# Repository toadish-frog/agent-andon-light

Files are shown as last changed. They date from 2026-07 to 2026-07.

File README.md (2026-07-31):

# Agent Andon Light





A physical desktop status light and vibe coding companion for Claude Code / CLI coding agents — so you can walk away while an agent works and still know its state at a glance, instead of staring at a terminal.

| | | | |
| :---: | :---: | :---: | :---: |
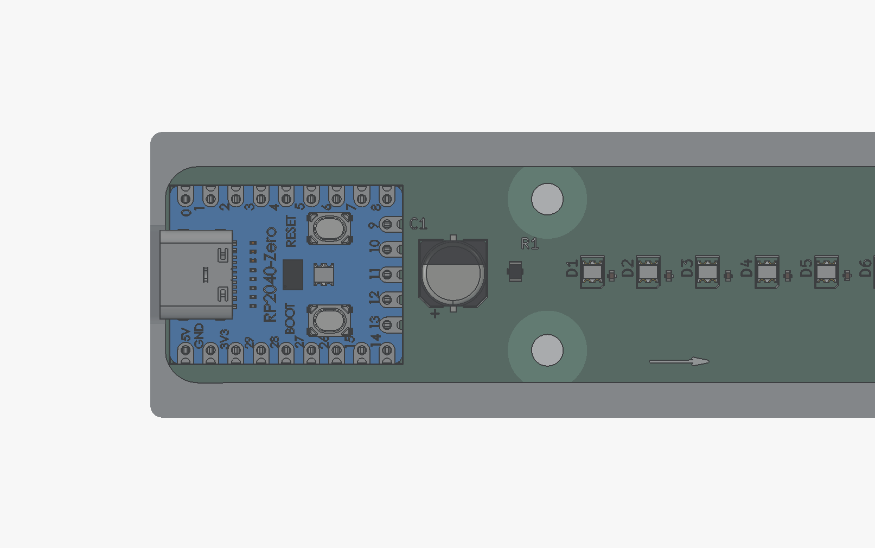
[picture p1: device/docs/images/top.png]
Top view
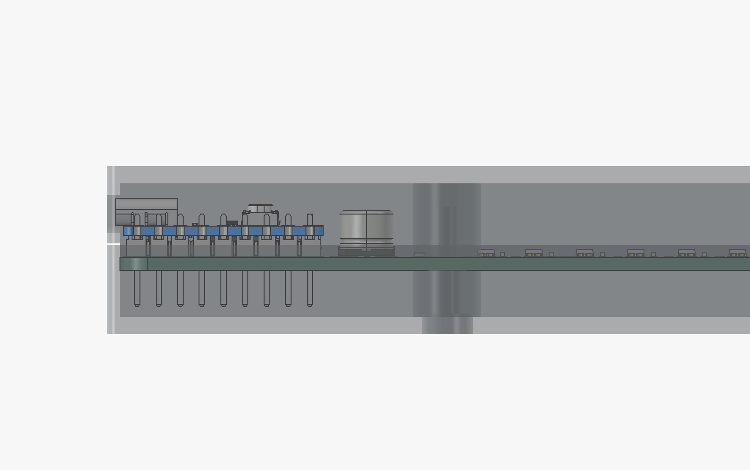
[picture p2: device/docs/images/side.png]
Side view
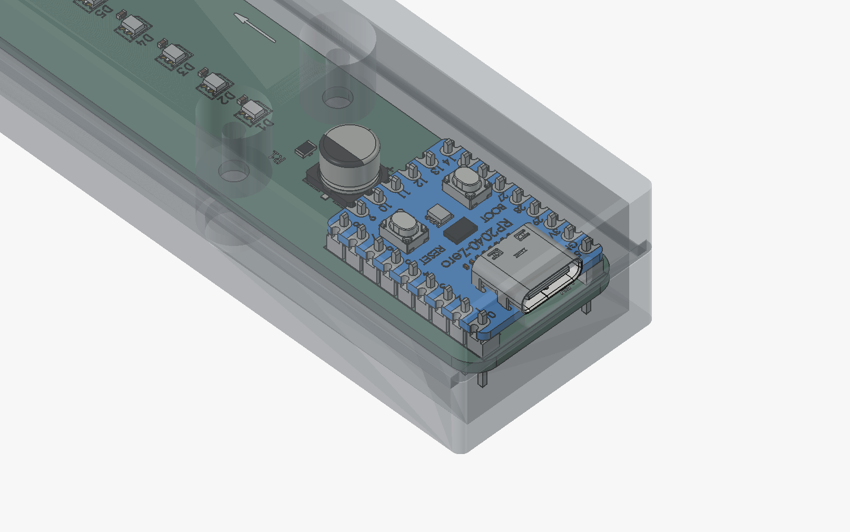
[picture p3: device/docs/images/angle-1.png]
Angle view
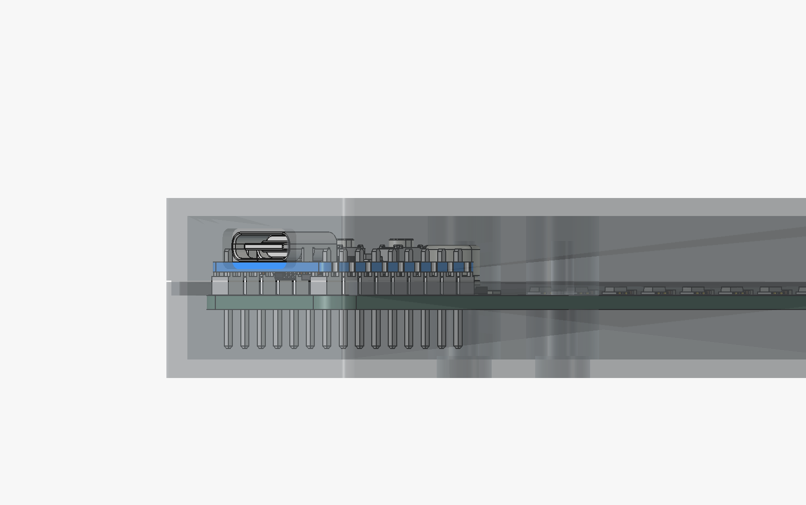
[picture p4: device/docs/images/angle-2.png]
Angle view
|  |  |  |  |

| | Color | Meaning |
| --- | --- | --- |
| 🟩 | Green | Agent working |
| 🟨 | Yellow | Waiting on you (permission or input) |
| 🟥 | Red | Idle / stopped / session ended |
| 🟩💫 | Flashing green | Compacting (internal maintenance, still alive) |
| 🟥〜 | Slow pulsing red | Stale / disconnected (device hasn't heard from the host in 30 min) |

This doc covers "I already have the hardware, how do I get it running." Building the hardware from scratch starts at [`device/docs/USER-GUIDE.md`](device/docs/USER-GUIDE.md).

## What You Need

- The assembled device — a Waveshare RP2040-Zero hand-soldered onto the custom PCB, **pre-flashed with firmware.** Building one from scratch instead? Start at [`device/docs/USER-GUIDE.md`](device/docs/USER-GUIDE.md), not here.
- A data-capable USB-C cable.
- Python 3 — Linux only. Windows doesn't need it; the installer is self-contained.

## Quick Start

**1. Plug in the device** with a data-capable USB-C cable.

**2. Install the host CLI.**

| OS | How |
| --- | --- |
| Linux | `pipx install andon-light` — see [`packaging/linux/README.md`](packaging/linux/README.md) |
| Windows | Download `andon-light-setup.exe` from [Releases](https://github.com/toadish-frog/agent-andon-light/releases) and run it — see [`packaging/windows/README.md`](packaging/windows/README.md) |

Confirm it can see the device:

```txt
andon-light doctor
```

**3. Wire up the Claude Code hooks:**

```txt
andon-light install-hooks
```

Shows you the exact hook config before touching anything, then merges it into `~/.claude/settings.json` (or a single project's config) once you confirm. Rationale for each hook mapping: [`hooks/README.md`](hooks/README.md).

**4. Restart Claude Code** (or start a new session) — hook config changes don't apply to a session already running.

From here the light tracks your session automatically — no manual commands needed day to day.

## Manual Control

Useful for testing, or to set the light by hand:

| Command | Effect |
| --- | --- |
| `andon-light set working` | 🟩 Solid green |
| `andon-light set waiting` | 🟨 Solid yellow |
| `andon-light set idle` | 🟥 Solid red |
| `andon-light set compacting` | 🟩💫 Chase-fill (compacting) |
| `andon-light heartbeat` | Keepalive, no color change |
| `andon-light doctor` | Detect the device and report its port |

## Troubleshooting

See [`device/docs/TROUBLESHOOTING.md`](device/docs/TROUBLESHOOTING.md) for the full diagnostic playbook, covering both Windows and Linux.

## Documentation

### Building & Hardware

- [User Guide](device/docs/USER-GUIDE.md) — build guide: soldering, wiring, glossary
- [Bill of Materials](device/docs/BOM.md) — parts list
- [Firmware](device/firmware/README.md) — firmware setup & wire protocol

### Software

- [Host CLI](host/README.md) — CLI development & usage
- [Claude Code Hooks](hooks/README.md) — hook mapping & rationale

### Installing

- [Linux Install](packaging/linux/README.md)
- [Windows Install](packaging/windows/README.md)

### Troubleshooting

- [Diagnostic Playbook](device/docs/TROUBLESHOOTING.md) — Windows + Linux

### Archive

- [3-Bulb MVP](archive/led-bulb-mvp/README.md) — earlier hardware iteration, not part of the current build

## Project Structure

```txt
agent-andon-light/
├── device/                 the only ongoing hardware line
│   ├── firmware/            Arduino sketch (C++) — drives the LED strip
│   ├── hardware/             KiCad schematic, PCB, manufacturing files
│   └── docs/                  BOM, user guide, troubleshooting, images
├── host/                   Python CLI (`andon-light`) — talks to the firmware over USB serial
├── hooks/                  Claude Code hook config that drives the CLI automatically
├── packaging/              OS-specific install/build tooling
│   ├── linux/                docs-only install path (pipx, no build step)
│   └── windows/               PyInstaller build + Inno Setup installer
├── scripts/                misc dev/demo scripts
└── archive/                retired hardware iterations, frozen history
    └── led-bulb-mvp/          3-discrete-bulb MVP, superseded by the strip
```

## Status

5 units built and tested — custom PCB, 3D-printed enclosure, firmware, host CLI, and Claude Code hooks all confirmed working end to end. Published on PyPI; a one-click Windows installer is available.

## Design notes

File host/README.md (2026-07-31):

# Host CLI: andon-light

Python driver for the Agent Andon Light. Talks to the firmware ([`../device/firmware/`](../device/firmware/)) over USB CDC serial via a simple text wire protocol.

## Layout

```txt
host/
├── pyproject.toml
├── andon_light/
│   ├── cli.py               # argparse entry point, `andon-light` command
│   ├── device_discovery.py  # finds the board by USB vendor ID
│   ├── serial_link.py       # opens/writes the serial connection, retry-on-busy
│   ├── hooks_install.py     # `andon-light install-hooks` merge/confirm logic
│   └── data/
│       └── settings.snippet.json   # bundled copy for installed/frozen builds
└── tests/
    └── test_hooks_install.py
```

## Install (development)

For actually using the CLI (Claude Code hooks, manual `andon-light` calls), install the published package instead — see [`../packaging/linux/README.md`](../packaging/linux/README.md) (Linux) or [`../packaging/windows/README.md`](../packaging/windows/README.md) (Windows). macOS isn't tested or supported yet.

To develop this repo, install in editable mode — symlinks back to source, so edits show up immediately without reinstalling:

```txt
cd host
pipx install --editable .
```

For an isolated venv, not on `PATH` outside it:

```txt
cd host
python3 -m venv .venv
.venv/bin/pip install -e .
```

## Usage

```txt
andon-light doctor                              # detect the device
andon-light set working                         # solid green
andon-light set waiting                         # solid yellow
andon-light set idle                             # solid red
andon-light set compacting                       # flashing green
andon-light heartbeat                            # keepalive, no color change
andon-light --port /dev/ttyACM0 set working      # override auto-detection
andon-light install-hooks                        # merge Claude Code hooks into settings.json
andon-light install-hooks --yes --scope global   # same, non-interactive (used by the Windows installer)
```

`install-hooks` prints the exact `hooks` block before touching anything, asks for confirmation, lets you pick global (`~/.claude/settings.json`) vs. project (`./.claude/settings.json`) scope, and warns before overwriting any hook event you've already customized. It never edits silently — see [`../hooks/README.md`](../hooks/README.md).

## Notes

- Auto-detection (`device_discovery.py`) filters by USB vendor ID `0x2E8A` (Raspberry Pi Foundation, used by arduino-pico's default TinyUSB descriptor) — matches the Waveshare RP2040-Zero.
- Override with `--port` or the `ANDON_LIGHT_PORT` env var if auto-detection picks the wrong port or finds nothing.
- "Device or resource busy" means another process (e.g. Arduino IDE's Serial Monitor) has the port open — only one process can hold it at a time. `andon-light` retries automatically for ~450ms before giving up; a serial failure then prints a one-line message with exit code 1 instead of a raw Python traceback.

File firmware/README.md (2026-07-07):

# Firmware — Agent Andon Light

Arduino sketch for the Waveshare RP2040-Zero, implementing the v2 wire protocol from `.prompt/docs/Implementation-Summary.md` (`G`/`Y`/`R`/`C`/`H`).

## Setup (once — see `.prompt/docs/USER-GUIDE.md` Phase 1 checklist)

1. Arduino IDE 2.x, with the `arduino-pico` board package installed. No LED library needed — the 3 status bulbs are plain `digitalWrite`/`analogWrite` GPIO, not an addressable protocol.
2. Open `andon_light_firmware/andon_light_firmware.ino` — Arduino IDE will load `led_controller.h/.cpp` and `watchdog.h` alongside it as tabs.

## Wiring

The status light is a custom PCBA with 3 discrete LED bulbs (Red/Yellow/Green) and a 4-pin connector: `GND`, `Red`, `Yellow`, `Green`.

- PCBA `GND` ← board `GND`
- PCBA `Green` ← `GPIO1`
- PCBA `Yellow` ← `GPIO2`
- PCBA `Red` ← `GPIO3`

Change the pins in `andon_light_firmware.ino` by editing `kGreenPin`/`kYellowPin`/`kRedPin` if you wire it differently. Note the RP2040-Zero uses plain GPIO numbers (`GPIO0`, `GPIO1`, ...), not the `D0`-style aliases Seeed's boards use — don't copy pin names from XIAO tutorials verbatim.

## Flash & test

1. Select "Waveshare RP2040-Zero" as the board, then flash.
2. Open the Serial Monitor at 115200 baud, line ending "Newline".
3. Type `G`, `Y`, `R` and press enter — confirm the LEDs respond. To test the stale-pulse fallback without waiting the full 30 minutes, temporarily lower `kWatchdogTimeoutMs` (e.g. to `15000`), flash, confirm the slow red pulse kicks in after that shorter wait, then change it back to `1800000` and reflash.

## Confirmed on real hardware (2026-07-07)

- `kGreenPin`/`kYellowPin`/`kRedPin` (`GPIO1`/`GPIO2`/`GPIO3`) — confirmed correct against the actual PCBA wiring via Serial Monitor testing.
- `StalePulse`'s `analogWrite` (PWM) breathing animation on the red pin — confirmed working on GPIO3.

## New in v2: flashing green (`C`)

Added 2026-07-07 alongside the `PostCompact` hook, for "still working, just doing internal context compaction" — visually distinct from solid green (`G`, ordinary working) via a sharp on/off blink (`kFlashPeriodMs = 500` in `led_controller.cpp`), as opposed to `StalePulse`'s slow smooth breathing fade. **Needs re-flashing** to take effect — this is source-level only until the sketch is re-uploaded.

## Power-on default: idle (red), not off

Added 2026-07-08 — the board's `setup()` used to leave all 3 bulbs off until the first serial command arrived. That's fine when Claude Code's `SessionStart` hook fires right after, but a bare USB replug/power-cycle is a hardware event Claude Code never sees, so the light would sit dark indefinitely until some other hook happened to fire. `LedController::begin()` now boots straight to `LightColor::Red` (idle) instead of `Off`, matching the same "not working yet" default reasoning as the `SessionStart` hook. **Needs re-flashing** to take effect. Note: replugging the USB cable does **not** erase or require re-flashing the firmware itself (it's stored permanently in flash memory) — this fix is only about what color it happens to boot into, not whether the program is still there.

## Watchdog timeout: 30 minutes, not 15 seconds

Originally 15s, raised to `kWatchdogTimeoutMs = 1800000` (30 min) after real-world testing with Claude Code hooks showed false stale-pulse trips: the hooks only fire at a few discrete moments (prompt submitted, tool used, waiting, stopped), so any gap longer than 15s between them — e.g. a long stretch of the model just thinking with no tool calls — incorrectly looked "disconnected." 30 minutes comfortably covers that while still eventually recovering if a session is genuinely abandoned mid-turn. See `../hooks/README.md` for the corresponding `PreToolUse` hook addition that keeps the watchdog kicked during tool-heavy stretches.

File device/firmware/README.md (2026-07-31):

# Firmware: Agent Andon Light

Arduino sketch for the Waveshare RP2040-Zero — drives a 10-LED addressable WS2812 strip via Adafruit_NeoPixel, speaking the wire protocol below over USB serial.

An earlier iteration used 3 discrete bulbs instead of an addressable strip — see [`../../archive/led-bulb-mvp/firmware/`](../../archive/led-bulb-mvp/firmware/) for that firmware, preserved but not maintained.

**This doc covers firmware only** (code, dependency, flashing, protocol). For physically building the device — soldering, wiring — see [`../docs/USER-GUIDE.md`](../docs/USER-GUIDE.md), the single source of truth for hardware assembly.

## Contents

- [Dependency: Adafruit_NeoPixel](#dependency-adafruit_neopixel)
- [Setup](#setup)
- [Flash & Test](#flash--test)
- [Reference](#reference)
  - [Power](#power)
  - [Pixel Layout](#pixel-layout)
  - [Wire Protocol Reference](#wire-protocol-reference)

## Dependency: Adafruit_NeoPixel

WS2812-style LEDs need sub-microsecond bit timing that plain `digitalWrite`/`analogWrite` can't produce. This sketch uses **Adafruit_NeoPixel** (Arduino Library Manager → search "Adafruit NeoPixel" → Install) — the standard driver for this chip family, with native RP2040/PIO support via `arduino-pico`.

## Setup

1. Arduino IDE 2.x, with the `arduino-pico` board package installed.
2. Install the Adafruit NeoPixel library (Tools → Manage Libraries).
3. Open `andon_light_firmware/andon_light_firmware.ino` — Arduino IDE loads `led_controller.h/.cpp` and `watchdog.h` alongside it as tabs.

Building the physical board (soldering the MCU on, or wiring a breadboard prototype) happens in [`../docs/USER-GUIDE.md`](../docs/USER-GUIDE.md) §2, before you get to Flash & Test below.

## Flash & Test

1. Select "Waveshare RP2040-Zero" as the board, then flash.
2. Open the Serial Monitor at 115200 baud, line ending "Newline".
3. Confirm pixel 1 alone is dim white and pixels 2-10 are dark (boot state).
4. Type `G`, `Y`, `R`, pressing enter after each — confirm only that color's 3-pixel section lights, rest stays dark.
5. Type `C` — confirm the chase-fill sweep described in [Pixel Layout](#pixel-layout) below.
6. To test `StalePulse` without waiting 30 minutes: temporarily set `kWatchdogTimeoutMs` to `15000`, flash, confirm the breathing red pulse on pixels 8-10, then set it back to `1800000` and reflash.

## Reference

### Power

Brightness is capped at `kBrightness = 130/255` (`led_controller.cpp`) for current draw and eye comfort — raise it if the strip is diffused behind a cover. If you're seeing flicker or wrong colors, that's a hardware issue (solder joint or wiring, depending on your build) — see [`../docs/USER-GUIDE.md`](../docs/USER-GUIDE.md) Pitfalls to Avoid, not a firmware setting.

### Pixel Layout

| Pixel | Role | Color |
| --- | --- | --- |
| 1 | Status, always on | Dim white |
| 2-4 | Green section | `G` → RGB(0,255,0) |
| 5-7 | Yellow section | `Y` → RGB(255,255,0) |
| 8-10 | Red section | `R` → RGB(255,0,0); watchdog stale → breathing red |

- Pixel 1 stays dim white through every state, including `Off` — a "board powered, firmware running" indicator, independent of the `G`/`Y`/`R` state color.
- `G`/`Y`/`R` each light only their own section; every other section (except pixel 1) goes dark.
- `StalePulse` (watchdog timeout) breathes the red section (8-10) with the same cosine curve, confined to that section.
- `CompactFlash` uses all 9 non-status pixels (2-10): a single lit pixel sweeps from pixel 10 down to pixel 2 and locks, the next sweep locks pixel 3 (skipping the now-locked pixel 2), and so on — pixels accumulate lit from pixel 2 upward, one per pass, until all 9 are lit, then it resets and repeats. See `kCompactPixelCount`/`kCompactStepMs` in `led_controller.cpp`.

See `led_controller.cpp`'s `kGreenStart`/`kYellowStart`/`kRedStart`/`kStatusPixel` constants for the implementation.

### Wire Protocol Reference

| Command | Effect | Meaning |
| --- | --- | --- |
| `G\n` | Pixels 2-4 solid green | Agent working |
| `Y\n` | Pixels 5-7 solid yellow | Waiting for human input / permission |
| `R\n` | Pixels 8-10 solid red | Idle / stopped / quota reached |
| `C\n` | Chase-fill across pixels 2-10 | Compacting — internal maintenance, still alive |
| `H\n` | No color change | Heartbeat, resets the watchdog |

Watchdog timeout: **30 minutes**.

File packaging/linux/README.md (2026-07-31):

# Linux Install & Verify

No installer to build — Linux is docs-only by design, published straight to PyPI. Linux users are assumed comfortable with a terminal.

## 1. Install

```txt
sudo apt install -y pipx   # if you don't have pipx yet
pipx install andon-light
```

No repo clone needed.

## 2. Verify

```txt
andon-light doctor
```

Confirms the CLI can find the board. If it reports a permission error, your user needs `dialout` group membership — see [`../../device/docs/TROUBLESHOOTING.md`](../../device/docs/TROUBLESHOOTING.md) Linux-Specific section.

## 3. Wire Up Claude Code Hooks

```txt
andon-light install-hooks
```

Prints the exact `hooks` block before touching anything, asks for confirmation, and lets you pick global (`~/.claude/settings.json`) vs. project (`./.claude/settings.json`) scope — see [`../../hooks/README.md`](../../hooks/README.md).

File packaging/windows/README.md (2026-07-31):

# Windows Installer: Build & Test

Everything here needs to run on Windows — build it there, not by cross-compiling from Linux.

## 1. Build the .exe

Prerequisites: Python 3.9+ on `PATH`.

```powershell
.\packaging\windows\build.ps1
```

Creates an isolated build venv at `packaging\windows\.build-venv` (doesn't touch any Python install you already have), builds `packaging\windows\dist\andon-light.exe` via PyInstaller, prints its size, and runs `andon-light.exe doctor` as a sanity check.

**Expected size:** low tens of MB — PyInstaller only bundles what's reachable from the entry point (`argparse` + `pyserial`, nothing exotic). If the size is much larger, check `packaging\windows\build\andon-light\warn-andon-light.txt` (PyInstaller's build log) for what got pulled in.

## 2. Build the Installer

Prerequisite: [Inno Setup](https://jrsoftware.org/isinfo.php).

```powershell
iscc packaging\windows\andon-light.iss
```

(Or open `andon-light.iss` in the Inno Setup IDE and click Compile.) Output: `packaging\windows\dist\andon-light-setup.exe`.

| Property | Behavior |
| --- | --- |
| Privilege | Per-user, no admin/UAC prompt |
| PATH | Adds itself to the user's `PATH` |
| Hooks | Finish-page checkbox runs `andon-light.exe install-hooks` — same confirm-before-writing flow as the CLI's interactive mode, see [`../../hooks/README.md`](../../hooks/README.md) |

## 3. SmartScreen Warning

Neither `andon-light.exe` nor `andon-light-setup.exe` is code-signed. Windows shows "Windows protected your PC" the first time either runs, and some antivirus engines may flag the PyInstaller `--onefile` binary outright — its self-extract-to-temp-dir behavior at runtime resembles a malware dropper. Neither means the build is broken.

| | |
| --- | --- |
| Fix | Click "More info," then "Run anyway." |
| Affects | Every recipient, not just test runs — pass along the click-through instructions with the installer. |
| Real fix, if ever needed | An Authenticode code-signing certificate (~$70–400/yr) removes the "Unknown Publisher" label; a new cert still needs to build SmartScreen reputation over time unless it's EV. Not worth it for a handful of known recipients. |

## 4. Verification Checklist

Test on real Windows hardware, not by inspection:

- [ ] **CDC driver** — RP2040-Zero enumerates as a COM port with zero extra steps, no `arduino-pico` INF needed.
- [ ] **PATH** — open a **new** terminal after installing (PATH changes don't apply to already-open ones) and confirm `andon-light doctor` resolves and finds the device.
- [ ] **install-hooks from the finish page** — checkbox launches a visible console window with the interactive prompt; declining/confirming both behave as expected.
- [ ] **Uninstall** — "Add or Remove Programs" cleanly removes both the `PATH` entry and the installed files. Inno Setup doesn't undo a `[Registry]` string append automatically — `andon-light.iss` has explicit `RemovePath`/`CurUninstallStepChanged` logic for this; verify it actually works.

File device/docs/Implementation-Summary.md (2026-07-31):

# Implementation Summary: Agent Andon Light

Internal reference for tech stack, architecture, and roadmap — dev/agent-facing, not tracked on the remote for outside readers. Update as decisions change.

The addressable WS2812 strip (`device/`) is the sole ongoing hardware line. An earlier 3-discrete-bulb MVP is archived at [`../archive/led-bulb-mvp/`](../archive/led-bulb-mvp/) — not a second deliverable, see History below for why it exists.

---

## 1. Technology Stack

### Hardware

| Part | Choice | Why |
| --- | --- | --- |
| MCU board | Waveshare RP2040-Zero | Native USB (no separate USB-UART chip), 23.5×18mm with castellated pads (hand-solderable), USB-C. Fully supported by Arduino IDE via `arduino-pico`. Onboard WS2812 RGB LED lets firmware/toolchain be smoke-tested before wiring anything external. |
| Status LEDs | Custom PCBA, WS2812-style addressable strip, 10 LEDs, wired via 3-pin connector (`S`/`V`/`G`) | Individually addressable per pixel over one data wire (`Adafruit_NeoPixel`), so each agent state owns a dedicated 3-pixel section instead of one shared color — see [Addressable Pixel Layout](#addressable-pixel-layout). |
| Cable / connector | 3-conductor wire or JST-style connector, plus a data-capable USB-C to USB-A cable to the host | 3 wires (`S`/`V`/`G`) MCU→strip; USB-C carries power + serial to the host. |
| Enclosure | 3D-printed diffuser + base | Passes light through 9 individually visible segments, not 3 discrete bulb positions. |

Full parts list: [`BOM.md`](BOM.md).

### Firmware

- **Language:** C++ (Arduino framework).
- **Library:** Adafruit_NeoPixel — required for WS2812 timing; can't be bit-banged reliably with plain GPIO calls.
- **Toolchain:** Arduino IDE (or Arduino CLI) with the `arduino-pico` board package.
- **Interface:** USB CDC serial — enumerates as a plain serial port on every OS, no custom driver needed on any of them.
- **Power:** must be 5V/`VBUS`, not 3.3V — 10 addressable LEDs draw meaningfully more current than a 3.3V regulator is meant to supply. Firmware caps brightness (`kBrightness = 130/255`) for draw and eye comfort.

### Host Driver Software

- **Language:** Python 3 — runs identically on Linux/Windows/macOS with minimal setup; `pyserial` + `pipx install andon-light` is far less friction than distributing compiled binaries per OS.
- **Key library:** `pyserial`.
- **Packaging:** pip-installable package (`andon-light`) exposing a CLI, published on PyPI.
- **Integration point:** Claude Code [Hooks](https://docs.claude.com/) — mapping and rationale in [`../../hooks/README.md`](../../hooks/README.md). Commands run synchronously (not `async`) — see History for why.
- **Known gap:** no hook fires on a user-initiated Esc/interrupt — not exposed by Claude Code's hook system. The light holds its last color through an Esc interrupt.
- **Unaffected by which firmware is flashed.** `host/andon_light/cli.py` maps each state to a single ASCII byte (`G`/`Y`/`R`/`C`) and writes it to whatever serial port `device_discovery.py` found — it has no idea how many LEDs are on the other end or how they're wired. That logic lives entirely in firmware. This is why `host/` and `hooks/` needed zero changes when the project moved from the bulb MVP to the strip.

---

## 2. Architecture

```txt
┌─────────────────────────┐
│  Claude Code / CLI agent│
│  (hooks fire on events) │
└───────────┬─────────────┘
            │ shell exec
            ▼
┌───────────────────────────┐
│  andon-light CLI (Python) │  ← ../../host/
└───────────┬───────────────┘
            │ USB CDC serial (identical text protocol)
            ▼
┌───────────────────────────┐
│  Firmware (C++/Arduino)   │  ← firmware/andon_light_firmware/
│  - parses commands        │
│  - drives 10 WS2812 pixels│
│    via Adafruit_NeoPixel  │
│  - watchdog / auto-idle   │
└───────────┬───────────────┘
            │ 1 GPIO data pin (+ 5V, GND)
            ▼
┌───────────────────────────┐
│  Custom PCBA, WS2812 strip│
│  10x addressable LEDs     │
└───────────────────────────┘
```

**Wire protocol:**

| Command | Effect |
| --- | --- |
| `G\n` | Working — green section solid |
| `Y\n` | Waiting — yellow section solid |
| `R\n` | Idle — red section solid |
| `C\n` | Compacting — chase-fill sequence |
| `H\n` | Heartbeat — no color change, resets watchdog |

**Reliability:** the firmware runs a watchdog timer — no heartbeat/command within **30 minutes** falls back to a slow-pulse red on the red section ("stale/disconnected") rather than silently freezing on a stale color if the host driver crashes. See History for how the timeout value was tuned.

### Addressable Pixel Layout

Each agent state owns a dedicated sub-range of the strip, rather than setting every pixel to the same color:

| Pixels (1-indexed) | Role | Color |
| --- | --- | --- |
| 1 | Status — always on | Dim white |
| 2-4 | Green section | `G` → solid green |
| 5-7 | Yellow section | `Y` → solid yellow |
| 8-10 | Red section | `R` → solid red; watchdog stale → breathing red (`StalePulse`) |
| 2-10 (all 9 non-status) | `C` (`CompactFlash`) | Chase-fill, not confined to one section |

For `G`/`Y`/`R`/`StalePulse`, only the active section's pixels are lit; every other section is off. Pixel 1 stays dim white through every state, including `Off`, as a constant "board is powered and firmware is running" indicator.

`CompactFlash` chase-fill spans all 9 non-status pixels: a single lit pixel sweeps from pixel 10 down to pixel 2 and locks, the next sweep locks pixel 3 (2 stays lit), and so on — pixels accumulate lit from pixel 2 upward, one per pass, until all 9 are lit, then it resets and repeats. This is a deliberately different rendering path from the other four states (`renderSection()` in `led_controller.cpp` doesn't cover it, since it needs two disjoint lit ranges at once).

**Boot behavior:** the strip boots to `Off` — dim-white status pixel only — since the status pixel alone already serves the "alive" signal, with no need to guess a placeholder state color.

---

## 3. Project Directory Structure

```txt
agent-andon-light/
├── README.md                   # top-level orientation + quick start
├── host/                        # Python driver package (andon-light CLI)
├── hooks/                       # Claude Code integration (settings.snippet.json + README)
├── packaging/                    # OS-specific distribution — windows/, linux/
└── device/                      # the only hardware line
    ├── firmware/
    │   ├── README.md
    │   └── andon_light_firmware/
    │       ├── andon_light_firmware.ino
    │       ├── led_controller.h/.cpp
    │       └── watchdog.h
    ├── hardware/                # KiCad schematic/PCB/manufacturing files — Rev A sent to JLC for fab
    │   ├── kicad/
    │   └── manufacturing/
    ├── archive/
    │   └── led-bulb-mvp/         # frozen 3-discrete-bulb breadboard MVP: firmware + docs
    └── docs/
        ├── BOM.md
        ├── Implementation-Summary.md   # this file
        ├── USER-GUIDE.md
        └── TROUBLESHOOTING.md
```

---

## 4. Roadmap

| # | Goal | Status |
| --- | --- | --- |
| 0 | Research & order parts | Done |
| 1 | Breadboard MVP (bulb PCBA, archived) | Done |
| 2 | Host CLI MVP | Done |
| 3 | Claude Code hook integration | Done |
| 4 | Reliability pass | Mostly done — live unplug/replug + long-turn stress test still outstanding |
| 5 | Custom PCB (strip) | Done — Rev A back from JLC, assembled, reflashed, electrically verified across all 5 units |
| 6 | Enclosure | Done — chassis base + lid 3D-printed via JLC, fit confirmed first-try on all 5 units |
| 7 | Packaging & distribution | Mostly done — PyPI published, `install-hooks` shipped, Windows installer built and verified on real hardware; Linux is docs-only by design, macOS deferred; GitHub release still outstanding |
| 8 | Stretch goals | Backlog — multi-agent/multi-light support, buzzer for alerts, ambient-light brightness sensing, user-configurable color mapping |

---

## 5. Open Items

- **Final brightness value** — `130/255` is a reasoned starting point (current draw + eye comfort), workable behind the actual diffuser, but not formally re-tuned against it.
- **Dim-white status pixel level** — `kDimWhiteLevel = 25` (pre-`kBrightness`-scaling) is a reasoned guess, not explicitly confirmed as the right dimness.
- **Per-unit cost at production quantity** — the 5-board sample order (PCB + assembly + enclosure) was priced well above what a larger MOQ run would cost; no clean per-unit figure logged.
- **macOS support** — deferred, no Apple hardware available to build, sign, or test on. Code-signing/notarization requirements unresearched.
- **`v0.1.0` GitHub release** — not yet cut. Last remaining item in Phase 7.

---

## 6. History

Chronological log of decisions and resolutions — the detail that used to be scattered across every section above now lives here instead.

| Date | Event |
| --- | --- |
| 2026-07-05 | Kickoff. MCU decision: Waveshare RP2040-Zero over XIAO RP2040 / Arduino Pro Micro clone. |
| 2026-07-07 | Bulb-MVP breadboard (Phase 1) flashed and confirmed: `G`/`Y`/`R` correct on physical bulbs, watchdog stale-pulse confirmed. Host CLI MVP (Phase 2) done: `andon-light doctor` auto-detected the board (`DEFAULT_VID = 0x2E8A`, confirmed via `udevadm`); `set working/waiting/idle` confirmed end-to-end. Claude Code hook integration (Phase 3) done: merged into `~/.claude/settings.json`, hook-to-color mapping fine-tuned same day. Reliability pass: hardened `host/andon_light/` error handling (clean one-line message + exit 1 instead of raw traceback), added retry-on-busy-port logic. Watchdog timeout raised from an initial 15s to 30 minutes after real Claude Code sessions showed false stale-triggers during long tool-call-free thinking stretches; `PreToolUse` hook added to keep the watchdog kicked during tool-heavy stretches. |
| 2026-07-08 | `SessionEnd` hook added — `Stop` alone doesn't fire on a user interrupt (Ctrl+C). `async: true` tried and reverted — caused hook commands to complete out of order, leaving the light on a stale color. |
| 2026-07-11 | Strip's own breadboard validation done (ahead of committing to a PCB layout): `kDataPin` confirmed as `GPIO1`; data-line signal integrity at 3.3V logic confirmed fine with a series resistor (level shifter kept as an available fallback); section boundaries (1 status + 3 green + 3 yellow + 3 red) confirmed against the physical 10-pixel strip; `CompactFlash` chase-fill flashed and confirmed working. Bulb variant's own Phase 5 (custom PCB) put on hold in favor of the strip going first. |
| 2026-07-14 | Project restructured: retired the parallel `led-bulb/`/`led-strip/` hardware tracks. Strip renamed from `led-strip/` to `device/` as the sole ongoing hardware line. Bulb MVP archived at `archive/led-bulb-mvp/`. |
| 2026-07-30 | Rev A PCB (5-board sample run) back from JLC — all 5 assembled, reflashed, and individually confirmed working: `G`/`Y`/`R`/`C` correct on the fabricated PCB's own traces, and `StalePulse` triggered and confirmed on real hardware for the first time (previously validated by code inspection only). Enclosure (chassis base + lid) 3D-printed via JLC alongside the PCB order — fit correct first-try on all 5 units, no reprint or redesign needed. Level-shifter footprint confirmed unnecessary on real hardware, left unpopulated. `andon-light` published to PyPI (v0.1.0, MIT licensed). `install-hooks` CLI subcommand shipped. |
| 2026-07-31 | Windows installer (PyInstaller + Inno Setup) built and verified on real Windows hardware: device enumerates as a COM port with zero extra driver steps, PATH resolves in a new terminal, `install-hooks` finish-page flow and uninstall (including a PATH-cleanup fix) both confirmed working. |

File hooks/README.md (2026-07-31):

# Claude Code Hook Integration: Agent Andon Light

`settings.snippet.json` maps agent events to `andon-light` CLI calls.

## Hook → Color Mapping

| Hook event | Color | Meaning |
| --- | --- | --- |
| `SessionStart` | idle (red) | Default state — a new session starts "not working yet" |
| `UserPromptSubmit` | working (green) | You just gave it something to do |
| `PreToolUse` | working (green) | Fires on every tool call — keeps the light green through tool-heavy stretches |
| `Notification` | waiting (yellow) | General "needs your attention" |
| `PermissionRequest` | waiting (yellow) | Specifically waiting on a permission decision (e.g. approve a `Bash`/`npm install` call) |
| `PreCompact` | flashing green (compacting) | Internal context compaction — still "alive," distinct from ordinary working |
| `Stop` | idle (red) | Turn/session ended normally |
| `SessionEnd` | idle (red) | Session terminated for any reason, including abrupt ones `Stop` doesn't cover |

Commands run synchronously, not `async` — see [Why Not `async`](#why-not-async) below. The `hooks` object from `settings.snippet.json` merges into `~/.claude/settings.json` (global) or a project's `.claude/settings.json`. This config has no visibility into what's wired up on the far side of the serial link — it just runs `andon-light` commands, and firmware ([`../device/firmware/`](../device/firmware/)) does the rest. Restart Claude Code (or start a new session) to pick up a config change.

## Design Notes

### `PreToolUse` Keeps the Watchdog Fed

`UserPromptSubmit`/`Notification`/`Stop` only fire at 3 discrete moments — nothing resets the firmware watchdog during a long stretch of tool calls in between, so the light can fall back to the stale/disconnected pulse mid-turn. `PreToolUse` fires on every tool invocation (reads, edits, bash commands) and sends `working`, so any tool-heavy turn keeps kicking the watchdog continuously. It doesn't cover a turn that's pure extended thinking with zero tool calls — there's no hook event for "still generating text" — so that gap is instead covered by a much longer firmware watchdog timeout (30 minutes); see [`../device/firmware/README.md`](../device/firmware/README.md).

### `PermissionRequest` vs. `Notification`

`PermissionRequest` is more precise than `Notification` alone for the specific "waiting on a permission approval" moment (e.g. approving a `Bash(npm install)` call). Both map to the same yellow action, so there's no harm in the overlap when `Notification` also fires for the same event.

### `PreCompact` Gets Its Own Color

Without a distinct color, a compaction pass would either stay on whatever color was last set (misleading if it was red/idle) or require another hook just to flip back afterward. Flashing green reads as "still alive, doing upkeep" at a glance, and naturally reverts to solid green (or whatever's next) once the following hook fires — no extra "compaction done" hook needed.

### `SessionStart` Makes the Default Deterministic

Without it, a new session inherits whatever color the previous session left behind — usually fine, since `Stop` already leaves it on idle/red, but not guaranteed if a prior session crashed mid-turn without a clean `Stop`. Setting idle explicitly on `SessionStart` removes that dependency on history.

### `SessionEnd` Catches Interrupts `Stop` Doesn't

Killing an active `claude` process with Ctrl+C (not just interrupting a turn) leaves the light stuck on whatever color was last set if only `Stop` is configured — `Stop` doesn't fire on user interrupts. `SessionEnd` fires on any termination reason (no matcher needed) and resets to idle (red). `Stop` stays alongside it so normal turn/session ends still resolve as fast as possible, without waiting on session teardown.

## Why Not `async`

Every command was originally `async: true`, to guarantee zero latency on real tool calls. `async` gives no ordering guarantee between hook invocations — only that each one is *launched* in order, not that it *finishes* in order. Each `andon-light set ...` call is a fresh Python process (spawn + import + open/close the serial port), measured at ~40-50ms — cheap, but not zero, and under load (e.g. a busy tool-heavy turn) that's enough jitter for a later-launched command to finish before an earlier one. Concretely: a session ends correctly on red (`Stop`), but a `Notification`/`PermissionRequest` command that fired earlier in the session had been delayed, and completes only after `Stop`'s `idle` command already landed — silently overwriting it with stale yellow.

Removing `async` makes Claude Code wait for each hook to finish before continuing, guaranteeing true event order. At ~40-50ms per call this isn't perceptible against real tool-call durations, so the latency `async` was meant to buy wasn't worth the ordering risk.

## Why Every Command Ends in `|| true`

If the board is ever unplugged or the CLI is run on a machine without it, every hook invocation would otherwise fail loudly in Claude Code's hook output on every single prompt — noisy and disruptive for something meant to be a passive status indicator. Revisit removing it once the host CLI has auto-reconnect / graceful missing-device handling, and a genuinely broken connection becomes worth surfacing instead of silently swallowing.

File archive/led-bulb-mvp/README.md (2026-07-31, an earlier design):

# Archived: 3-Discrete-Bulb MVP

**Frozen history, not a maintained deliverable.** The original breadboard MVP hardware/firmware — a custom PCBA with 3 discrete LED bulbs (Red/Yellow/Green) on a 4-pin connector — used to validate the firmware/host-CLI/Claude-Code-hooks pipeline end-to-end before the addressable WS2812 strip (this project's sole ongoing hardware line) existed as a custom PCB.

## Why It's Here Instead of Deleted

The firmware and docs in this folder are real, working, confirmed-on-hardware artifacts — the actual history of how the wire protocol, watchdog, and hook mapping were designed and validated.

## Not Maintained Going Forward

- Not rebuilt or retested against the current `host/`/`hooks/` — those are unchanged and still protocol-compatible in principle (same `G`/`Y`/`R`/`C`/`H` bytes), but this firmware hasn't been re-flashed or re-verified since the pivot.
- Docs reflect the state and understanding at the time this hardware was active — later corrections made to the live docs (e.g. hook naming, driver confirmations) aren't backported here.

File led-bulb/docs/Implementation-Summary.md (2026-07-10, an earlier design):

# Implementation Summary: Agent Andon Light

*Generated from `.prompt/arch/ARCH-prompt.md`. This is the living reference for the project's tech stack, architecture, structure, and roadmap. Update it as decisions change — treat it as project memory, not a one-time snapshot.*

---

## 1. Recommended Technology Stack

### Hardware

| Part | Recommendation | Why |
| --- | --- | --- |
| MCU board | **Waveshare RP2040-Zero** | Native USB (no separate USB-UART chip), thumbnail-sized (23.5×18mm) with castellated pads (easy to hand-solder onto a custom PCB later), USB-C, ~¥30. Fully supported by Arduino IDE via the same `arduino-pico` board package as the XIAO — one-time setup, then standard Arduino workflow. Bonus: has its own onboard WS2812 RGB LED (GPIO16), so firmware/toolchain can be smoke-tested before wiring anything external. Switched from the originally-proposed Seeed XIAO RP2040 on 2026-07-05 — functionally equivalent, this one's onboard LED edged it out; only firmware-level difference is pin naming (`GPIO0`-style, not XIAO's `D0`-style aliases). |
| Status LEDs | **Custom PCBA, 3x discrete LED bulbs** (Red/Yellow/Green), wired to the MCU via a 4-pin connector (`GND`, `Red`, `Yellow`, `Green`) | Swapped from an addressable WS2812B strip on 2026-07-07 — user already has this custom PCBA in hand. Each bulb is its own simple on/off GPIO output instead of a single-wire addressable protocol; current-limiting resistors for each bulb live on the PCBA itself, not as separate breadboard parts. Simpler to drive (`digitalWrite`, no timing-sensitive protocol) at the cost of losing full-RGB/animatable color — fine here since the product only ever needs 3 fixed colors. |
| Cable / connector | 4-conductor wire or JST-style connector matching the PCBA's header, plus USB-C to USB-A cable (data-capable) to the host | 4 wires (`GND`+3 signal) from MCU GPIOs to the PCBA; USB-C carries power+serial to the host computer. |
| Enclosure (Phase 2) | 3D-printed or laser-cut diffuser + base | Cheap to iterate on locally or via a print-on-demand service. |

No part on this list is export-restricted or unusual — it's a commodity microcontroller and commodity LEDs, the same components used in countless hobbyist keyboards and lamps.

### Firmware

- **Language:** C++ (Arduino framework) — matches your instinct toward C, and it's the path with the most tutorials, the most stability, and the least setup for RP2040.
- **Library:** none needed for the LEDs — 3 discrete bulbs are driven with plain `digitalWrite`/`analogWrite`, no NeoPixel/FastLED dependency (that was only needed for the addressable WS2812B approach, now dropped).
- **Toolchain:** Arduino IDE (or Arduino CLI once you're comfortable) with the `arduino-pico` board package.
- **Interface:** USB CDC serial — the board enumerates as a plain serial port on every OS, no custom driver needed on Linux/macOS; Windows may auto-install a CDC driver or need the one-time `arduino-pico` INF.

### Host Driver Software

- **Language: Python 3.** This is a deliberate deviation from "maybe C" for the *host* side only (firmware stays C++): the host needs to run identically on Linux/Windows/macOS with minimal setup, and `pyserial` + a `pipx install andon-light` is dramatically less friction than distributing compiled C binaries for three OSes. C remains the right call for firmware, where Arduino's C++ toolchain is the standard anyway.
- **Key library:** `pyserial` for the serial link.
- **Packaging:** a small pip-installable package (`andon-light`) exposing a CLI.
- **Integration point:** Claude Code [Hooks](https://docs.claude.com/) — `SessionStart` → `andon-light set idle` (default state), `UserPromptSubmit`/`PreToolUse` → `andon-light set working`, `Notification`/`PermissionRequest` → `andon-light set waiting`, `PostCompact` → `andon-light set compacting` (flashing green), `Stop` → `andon-light set idle`. This is what makes the light "driven directly by the agent" per your design vision, with zero manual polling. Commands run synchronously (not `async`) — each call is only ~40-50ms, and `async` was found to cause an ordering race (a delayed early-turn command could overwrite a later, correct one — see `hooks/README.md` "Why not async"). Fine-tuned 2026-07-07 after real-session testing — see `hooks/README.md` for the reasoning behind each mapping.
- **Known gap:** no hook fires on a user-initiated Esc/interrupt — confirmed against the official docs, this event isn't currently exposed by Claude Code's hook system (`Stop` only fires when Claude finishes a turn naturally, not on cancellation). The light will hold its last color through an Esc interrupt rather than reflecting it. Not fixable at the hooks-config layer; would need a different integration approach if this becomes a priority.
- **Planned: one-click cross-platform installer (added 2026-07-08).** This was in the original RFP from the start (`.prompt/arch/ARCH-prompt.md` §2: *"As a everyday product user, I want to plug this andon light device to the computer with minimal setup, so that I can quickly use this product without having to spend too much time configuring the environment"*; §3 target platforms: Linux → Windows → macOS, all three checked as required Desktop App targets) but hadn't been scoped until now, after personally hitting the friction firsthand (missing `python3-venv`/`pip`/`pipx`, PEP 668's externally-managed-environment block, `libfuse2` for the Arduino IDE AppImage). Recommended approach: package `andon-light` itself as a **standalone binary per OS via PyInstaller** (bundles the Python interpreter + `pyserial`, so an end user needs zero pre-existing Python/pip/pipx — sidesteps every install-friction issue hit today), wrapped in a minimal first-run installer that (1) places the binary on `PATH`, and (2) interactively offers to merge the Claude Code hooks — see Phase 7 below for the full breakdown, including the explicit-permission requirement for touching `~/.claude/settings.json`.

---

## 2. Proposed Architecture

```txt
┌─────────────────────────┐
│  Claude Code / CLI agent│
│  (hooks fire on events) │
└───────────┬─────────────┘
            │ shell exec
            ▼
┌───────────────────────────┐
│  andon-light CLI (Python) │  ← host/
│  - device discovery       │
│  - serial protocol client │
│  - heartbeat daemon       │
└───────────┬───────────────┘
            │ USB CDC serial (simple text protocol)
            ▼
┌───────────────────────────┐
│  Firmware (C++/Arduino)   │  ← firmware/
│  - parses commands        │
│  - drives 3 discrete LEDs │
│  - watchdog / auto-idle   │
└───────────┬───────────────┘
            │ 3 GPIO pins (+ shared GND)
            ▼
┌───────────────────────────┐
│  Custom PCBA, 3x LED bulbs│
│  Green / Yellow / Red     │
└───────────────────────────┘
```

**Layering rationale:** three clean, independently testable layers — firmware (device logic), host CLI (transport + OS integration), and the hook glue (policy: *which* agent event maps to *which* color). Each layer can be developed and tested standalone before wiring the next one on, which matters a lot for someone learning hardware for the first time: you get a working LED blink before you touch serial, and a working serial round-trip before you touch Claude Code hooks.

**Wire protocol (v2, deliberately simple):**

```txt
G\n   → solid green    (agent working)
Y\n   → solid yellow   (waiting for human input / permission)
R\n   → solid red      (idle / stopped / quota reached)
C\n   → flashing green (compacting — internal maintenance, still "alive")
H\n   → heartbeat (no color change, resets watchdog)
```

`C` (flashing green) was added 2026-07-07 to distinguish "still working, just doing internal context compaction" (`PostCompact` hook) from ordinary solid-green "working," per the fine-grained hook mapping in §1 Integration point below. Visually distinct on purpose: `C` is a sharp on/off blink (500ms period), `StalePulse` (the watchdog fallback, not part of the normal protocol — see §2 Reliability design point) is a slow smooth breathing fade — so a user glancing at the light can tell "busy with maintenance" from "may be disconnected" at a glance.

**Reliability design point:** the whole premise of this device is that the user *walks away and trusts it*. So the firmware runs a watchdog timer — if no heartbeat or command arrives within **30 minutes** of the last one, it falls back to a distinct slow-pulse red ("stale/disconnected"), rather than silently freezing on a stale "green" if the host driver crashes. This single detail is the difference between a toy and something you can actually trust unattended.

Originally set to ~15s, then raised to 30 minutes (2026-07-07) after real Claude Code sessions showed it false-triggering: hooks only fire at a few discrete moments (prompt submitted, tool used, notification, stop), and any gap longer than 15s between them — most commonly a long stretch of the model just thinking with no tool calls — incorrectly looked like a dead connection. A `PreToolUse` hook was also added so any tool-heavy stretch keeps kicking the watchdog continuously; the 30-minute timeout is the remaining safety net for the rarer case of a turn that's pure thinking with zero tool calls.

---

## 3. Proposed Project Directory Structure

```txt
agent-andon-light/
├── .prompt/                    # planning docs (this RFP workflow) — existing
│   ├── arch/                   # architecture prompts + this summary
│   ├── docs/                   # BOM, build guide, glossary (see below)
│   ├── feat/                   # future feature prompts, one per roadmap phase
│   └── fix/                    # bugfix prompts
│
├── firmware/                    # Arduino IDE sketch for the Waveshare RP2040-Zero (per Phase 0 setup)
│   ├── README.md                # wiring, flashing, and Serial Monitor test steps
│   └── andon_light_firmware/
│       ├── andon_light_firmware.ino  # setup/loop, serial command parsing
│       ├── led_controller.h/.cpp     # 3-pin discrete LED driver, color states, stale-pulse animation
│       └── watchdog.h                # heartbeat timeout → stale-state fallback (header-only)
│
├── host/                       # Python driver package
│   ├── README.md                # install + usage
│   ├── pyproject.toml
│   └── andon_light/
│       ├── __init__.py
│       ├── cli.py              # `andon-light set|heartbeat|doctor`
│       ├── serial_link.py       # open/write logic
│       └── device_discovery.py # find the board by VID, or ANDON_LIGHT_PORT/--port override
│
├── hardware/                   # Phase 2: custom PCB (not started)
│   ├── kicad/                  # schematic + layout project
│   └── enclosure/              # 3D-printable diffuser/base STL/STEP files
│
├── hooks/                      # Claude Code integration
│   ├── README.md                # how/when to merge this, and why commands end in `|| true` for now
│   └── settings.snippet.json   # example hooks config to merge into settings.json
│
└── README.md                   # top-level orientation + quick start for users who already have the hardware
```

`firmware/`, `host/`, and `hooks/` now exist as working scaffolds (written ahead of parts arriving, since none of this needed hardware to write or unit-test — see the Phase 0/1/2/3 notes below for what's verified vs. still an assumption). `hardware/` (Phase 5, custom PCB) is still just a placeholder for later.

---

## 4. Project Style & Delivery Timeline

### Methodology: Phase-Gated Kanban

Not Scrum, not pure waterfall — a hybrid that fits a solo builder mixing hardware and software:

- **Phase-gated** because hardware forces real sequential dependencies a sprint board can't paper over — you can't do Phase 5 (custom PCB) before Phase 1–4 prove the firmware/host/hook logic actually works, and you can't do anything in a phase until the parts for it have physically arrived. That's a waterfall trait, and pretending otherwise just creates rework.
- **Kanban, not fixed sprints,** within and across phases — because the two things that block you (a parts shipment, a PCB fab run) don't respect a 2-week sprint boundary. A single-piece-flow board (`Backlog → In Progress → Blocked (shipping/fab) → Done`) reflects reality better than committing to sprint goals you can't control the input to.
- **Agile-style short feedback loops *within* each phase** — each phase is still scoped to end in something you can see or hold (a blinking LED, a working CLI call, a live Claude Code demo), rather than batching all design work before any hands-on testing.

Track progress with the table in §4.2 below — update the Status column as you go. Treat it as a living tracker, not a commitment device.

### Timeline Assumptions

- Solo, part-time hobbyist pace (~5–8 hours/week) — you said "learn as I build," so estimates include a first-timer's learning curve on Arduino and (later) KiCad, not an experienced maker's pace.
- Parts shipping: ~1–5 days (varies by supplier).
- PCB fab + shipping: ~1 week for a standard (non-expedited) small-batch order — noticeably faster than the original international-shipping estimate this replaced.
- **Kickoff: 2026-07-05** (today).

### 4.1 Roadmap Tracking Table

| Phase | Goal | Est. Duration (elapsed) | Est. Effort | Status |
| --- | --- | --- | --- | --- |
| 0 | Research & Order Parts | 3–7 days (shipping is fast) | 3–5 hrs | **Done** — RP2040-Zero + custom LED PCBA in hand, soldered and wired |
| 1 | Breadboard MVP (firmware only) | ~1 week | 5–8 hrs | **Done** — flashed to real hardware 2026-07-07; `G`/`Y`/`R` confirmed correct on the physical bulbs, watchdog stale-pulse confirmed (drops to breathing red after ~15–18s with no heartbeat) |
| 2 | Host CLI MVP | 3–5 days | 4–6 hrs | **Done** — installed in a venv, `andon-light doctor` auto-detected the board (VID `0x2E8A` guess confirmed correct via `udevadm`), `andon-light set working/waiting/idle` confirmed end-to-end against real hardware |
| 3 | Claude Code Hook Integration | 2–3 days | 3–4 hrs | **Done** — merged into `~/.claude/settings.json` (global), `andon-light` on `PATH` via `pipx`. Fine-tuned twice from real-session feedback: expanded to 7 hook events (`SessionStart`, `UserPromptSubmit`, `PreToolUse`, `Notification`, `PermissionRequest`, `PostCompact`, `Stop`), added a 4th LED state (flashing green for compaction), and fixed an `async`-induced ordering race (see §5 Phase 3 and `hooks/README.md`) |
| 4 | Reliability Pass | ~1 week | 5–6 hrs | **Mostly done (2026-07-07)** — watchdog tuned from real usage, CLI error handling hardened (clean messages + busy-retry, no more raw tracebacks), auto-reconnect found to be N/A given the one-shot-CLI architecture actually built. Remaining: live unplug/replug + long-turn stress test, needs the user present |
| 5 | Custom PCB | 1–2 weeks (design + fab/ship) | 10–15 hrs | **On hold (2026-07-11)** — deprioritized in favor of the **led-strip** variant's Phase 5, chosen to go first (see `../../led-strip/docs/Implementation-Summary.md` §6). This variant itself is fully functional and validated (Phases 0-4 all Done) — it's just not the one getting a custom PCB right now. Plan below remains valid if bulb is revisited later. |
| 6 | Enclosure | ~1 week | 4–6 hrs | Not Started |
| 7 | Packaging & Distribution | 3–5 days | 4–5 hrs | Not Started — scope expanded 2026-07-08 to explicitly include a one-click cross-platform installer + permission-gated hooks merge (was in the original RFP, just not scoped until now) |
| 8 | Stretch Goals | Open-ended | — | Backlog |

**Projected delivery** (elapsed calendar time, phases can overlap slightly where shipping waits allow parallel work):

- **Working breadboard MVP**, hooked into a live Claude Code session (Phases 0–4): ~4 weeks from kickoff → around **2026-08-02**.
- **Finished v1** with custom PCB + enclosure (Phases 0–6): ~6–7 weeks from kickoff → around **2026-08-23**.

Total hands-on effort through Phase 6 is roughly **35–50 hours** — fast parts and PCB fab turnaround cuts several weeks off the original international-shipping estimate, so elapsed time now tracks closer to actual effort than to logistics waits. These dates will still drift; re-baseline them once Phase 0 parts actually land, since that's the first real signal on your actual pace.

---

## 5. Development Roadmap — Detailed Phase Breakdown

### Phase 0 — Research & Order Parts

*Est. 3–7 days elapsed (shipping) · 3–5 hrs effort*

- Install Arduino IDE 2.x; add the `arduino-pico` board-manager URL; install the RP2040 board package (no LED library needed — 3 discrete bulbs are driven with plain `digitalWrite`/`analogWrite`).
- Order the Phase 1 BOM (`BOM.md`).
- **Deliverable:** parts in transit, dev environment ready to go the moment they arrive.
- **Done ahead of schedule while parts ship:** the Phase 1 firmware sketch, Phase 2 host CLI, and Phase 3 hooks config were all written now, since none of them needed hardware to write — see `firmware/`, `host/`, `hooks/`. Still outstanding for Phase 0 itself: installing Arduino IDE and actually placing the parts order.

### Phase 1 — Breadboard MVP (firmware only)

*Est. ~1 week · 5–8 hrs effort*

- Wire the Waveshare RP2040-Zero to the custom PCBA's 4-pin connector (`GND`, `Red`, `Yellow`, `Green`) per `USER-GUIDE.md` — 3 GPIO outputs + shared ground, no breadboard strictly required.
- Flash a test sketch that cycles red → yellow → green.
- Extend it to parse single-character serial commands (`G`/`Y`/`R`) from the Arduino Serial Monitor.
- **Deliverable:** a light that changes color on typed commands — first tangible proof the hardware works.
- **Blocked by:** Phase 0 parts arriving.
- **Status: Done (2026-07-07).** Flashed to the real Waveshare RP2040-Zero via Arduino IDE (AppImage, `--appimage-extract-and-run` since the sandboxed launch environment couldn't mount FUSE directly). First upload required manually forcing BOOTSEL mode (hold BOOT while replugging USB) since the auto-reset trick only works once an `arduino-pico` sketch has run at least once. Serial Monitor confirmed `G`/`Y`/`R` drive the correct bulbs and the watchdog correctly falls back to a slow breathing red after ~15–18s of no heartbeat. The `GPIO1`/`GPIO2`/`GPIO3` pin assignments are now **confirmed correct** against the actual wiring, not just placeholders.

### Phase 2 — Host CLI MVP

*Est. 3–5 days · 4–6 hrs effort*

- Scaffold the `andon-light` Python package (`pyproject.toml`, `andon_light/`).
- Implement `serial_link.py` (open/write over `pyserial`) and a minimal `cli.py` with `andon-light set <color>`.
- **Deliverable:** `andon-light set green` typed in a terminal changes the physical LED — end-to-end terminal → USB → LED.
- **Blocked by:** Phase 1 firmware command parser working.
- **Status: Done (2026-07-07).** Installed into a venv (`python3 -m venv .venv && pip install -e .`) after installing `python3-venv`/`python3-pip`. `andon-light doctor` auto-detected the board on the first try — `DEFAULT_VID = 0x2E8A` was confirmed correct via `udevadm info` against the real Waveshare RP2040-Zero, no fix needed. `andon-light set working/waiting/idle` all confirmed to correctly change the physical LED. One environment gotcha hit along the way: the serial port returned "Device or resource busy" until Arduino IDE's own Serial Monitor was disconnected — only one process can hold a serial port at a time.

### Phase 3 — Claude Code Hook Integration

*Est. 2–3 days · 3–4 hrs effort*

- Write `hooks/settings.snippet.json` mapping `UserPromptSubmit`/`PreToolUse` → working, `Notification` → waiting, `Stop` → idle.
- Merge into a real `settings.json` and run a live Claude Code session against the device.
- **Deliverable:** the actual product, working on a breadboard — the agent drives the light with zero manual intervention.
- **Blocked by:** Phase 2 CLI working standalone.
- **Status: Done (2026-07-07).** `andon-light` installed globally via `pipx install --editable .` (confirmed on `PATH`). The `hooks` object from `hooks/settings.snippet.json` merged into `~/.claude/settings.json` (global scope, user's choice — applies to every Claude Code session on this machine, not just this repo). All 3 hook commands (`andon-light set working/waiting/idle`) smoke-tested manually and confirmed working against the real hardware. `|| true` kept intentionally for now (see `hooks/README.md`) until Phase 4's reliability pass makes a genuinely broken connection worth surfacing loudly. Takes effect on Claude Code restart / new sessions — not the session it was configured from.

### Phase 4 — Reliability Pass

*Est. ~1 week · 5–6 hrs effort*

- ~~Add the firmware watchdog (stale-state fallback if no heartbeat)~~ — done ahead of schedule in Phase 1; timeout tuned from 15s to 30 min on 2026-07-07 after real-world hook testing (see §2 Reliability design point).
- ~~Add host-side auto-reconnect on USB replug~~ — **N/A given the architecture actually built.** This bullet assumed a persistent background daemon (note "kill the daemon" below, from the original design). What got built instead is a fresh one-shot `andon-light` CLI process per hook event — each call does its own device discovery, opens the port, sends, and closes. There's no persistent connection to go stale, so a replug is inherently handled by the next hook's normal invocation. Device auto-detection by VID was already done and confirmed in Phase 2.
- **Done (2026-07-07):** hardened `host/andon_light/` error handling — `cli.py` previously let a busy/missing port raise an unhandled Python traceback; now catches `serial.SerialException` and prints a clean one-line message with exit code 1 (still absorbed by hooks' `|| true`, but no longer noisy for standalone CLI use). `serial_link.py` now retries opening the port up to 3x (150ms apart) specifically on a "busy" error, to ride out the case where two hook-triggered calls land close together. Verified: clean error message on a nonexistent port (no traceback), normal calls still ~40-50ms (retry logic doesn't slow the common case). **Not independently verified:** a live two-process race against a kernel-level `TIOCEXCL` lock (the actual mechanism behind the earlier Arduino-IDE-Serial-Monitor conflict) — pyserial's own `exclusive=True` uses advisory `flock` instead, which doesn't reproduce that lock type, so this is trusted by code inspection rather than a clean repro.
- **Still needs a live session to validate** (can't be done without the user physically present): unplug/replug mid-session, and a real long-running turn stress test — the 30-min watchdog and `PreToolUse` kicks are reasoned to cover this (see §2), but haven't been observed end-to-end yet.
- **Deliverable:** something you can trust to run unattended — the actual bar for "walk away."
- **Blocked by:** Phase 3 end-to-end flow working.

### Phase 5 — Custom PCB

**Status: On hold (2026-07-11)** — see §4.1. The **led-strip** variant was chosen to go first for a custom PCB, since it reached a fully-validated state (firmware, host CLI, hooks, power all confirmed on real hardware) before this variant's own Phase 5 was picked up. This plan remains valid and ready to resume if the bulb variant is revisited later.

*Est. 1–2 weeks (design + fab/ship) · 10–15 hrs effort*

- Learn just enough KiCad to place the RP2040-Zero and route it to the LED PCBA's connector (or integrate the 3 discrete LEDs + resistors directly onto one board, if consolidating).
- Route a 2-layer board; run DRC; export Gerbers.
- Send CAD to a PCB fab service; order 5–10 boards (see `BOM.md` for the parts list).
- Hand-solder (or use the fab's assembly service, if you want them to place and solder the SMD parts for you).
- **Deliverable:** first real PCBA.
- **Blocked by:** Phase 4 firmware/protocol being stable — don't lock in a PCB layout around a protocol that's still changing.

### Phase 6 — Enclosure

*Est. ~1 week · 4–6 hrs effort*

- Design a simple diffuser + base (3D-printable or laser-cut).
- Prototype locally if you have access to a printer, or ride along with the PCB order's add-on services, if the fab offers them.
- **Deliverable:** looks like a product, not a breadboard.
- **Blocked by:** Phase 5 PCB dimensions being final (the enclosure has to fit the actual board).

### Phase 7 — Packaging & Distribution

*Est. 3–5 days · 4–5 hrs effort — scope expanded 2026-07-08, estimate likely needs revisiting once installer tooling is chosen*

- Publish the `andon-light` pip package (still useful for dev/editable installs, per `host/README.md`'s `--editable` vs plain distinction).
- Write install docs; test on Windows and macOS (CDC driver quirks are the most likely surprise here).
- **One-click installer, one per OS (Linux/macOS/Windows) — required by the original RFP, not a stretch goal.** Package `andon-light` as a standalone executable via **PyInstaller** (no separate Python/pip/pipx needed by the end user — directly solves the exact friction hit today: missing `python3-venv`, PEP 668 blocking a plain `pip install`, needing `pipx` installed first). Rough shape:
  - **Linux:** AppImage or a simple tarball + install script that drops the binary in `~/.local/bin`.
  - **Windows:** an installer built with something like Inno Setup wrapping the PyInstaller `.exe`, adding it to `PATH`.
  - **macOS:** a `.pkg` or drag-to-Applications `.app` — flag now, honestly, that **unsigned macOS binaries get blocked by Gatekeeper by default**, so "one-click" on macOS may actually mean "one right-click → Open" unless code-signing/notarization gets set up (a paid Apple Developer account), which is a real scope decision to make explicitly rather than discover late.
- **Hooks merge, bundled into the same installer, with explicit permission — required, not optional.** The installer must never silently edit `~/.claude/settings.json` (or a project's `.claude/settings.json`) — it's a shared config file affecting every Claude Code session, same principle already applied by hand this whole project (see `hooks/README.md`). On first run, the installer should: show the user exactly what `hooks` block it wants to add, ask for explicit confirmation (a real terminal/dialog prompt — "Add Claude Code hooks to ~/.claude/settings.json? [y/N]"), let them pick global vs. project scope (same choice made manually in Phase 3), and only write after an explicit yes. Treat a "no" as a supported outcome, not an error — the CLI should still be fully usable via manual `andon-light set ...` calls without the hooks.
- **Deliverable:** someone else — with zero Python/Arduino/CLI experience — downloads one file, runs it, answers one permission prompt, plugs in a pre-flashed device, and it works. This is the actual bar implied by the original RFP's "minimal setup" user story, not just "there's a pip package now."

### Phase 8 — Stretch Goals

*Open-ended, backlog — not on the critical path to v1*

- Multi-agent/multi-light support, buzzer for alerts, ambient-light brightness sensing, user-configurable color mapping.

---

## 6. Open Questions for You

- ~~XIAO RP2040 vs. Arduino Pro Micro clone~~ — resolved 2026-07-05: switched to the **Waveshare RP2040-Zero** (see §1 MCU board row for why). The Pro Micro (ATmega32U4) remains a valid fallback if RP2040 boards ever become hard to source, but isn't the current plan.
- ~~Heartbeat interval / timeout values~~ — resolved 2026-07-07: tuned from 15s to 30 min after real Claude Code session testing showed false stale-pulse trips (see §2 Reliability design point).
- ~~Hook-to-color mapping~~ — resolved 2026-07-07: expanded past the original 3-color proposal to 7 hook events / 4 LED states (added `PermissionRequest`, `PostCompact`→flashing-green, `SessionStart`→idle-default) — see `hooks/README.md`.
- **Installer tooling choice (added 2026-07-08)** — PyInstaller is recommended in §1/Phase 7 above, but not yet built or tested on any platform. Worth deciding early whether macOS code-signing/notarization (a paid Apple Developer account) is in scope, since it changes both the cost and the "how one-click is 'one-click,' really" answer for that platform specifically.

Next step: turn Phase 1 into a `.prompt/feat/` prompt when you're ready to start building.

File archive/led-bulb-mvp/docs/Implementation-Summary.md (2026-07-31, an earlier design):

# Implementation Summary: Agent Andon Light (3-Bulb MVP)

Internal reference for the archived 3-discrete-bulb variant — dev/agent-facing, not tracked on the remote. Frozen history: this variant is retired in favor of the addressable LED strip (see [`../../../device/docs/Implementation-Summary.md`](../../../device/docs/Implementation-Summary.md)), not actively maintained.

---

## 1. Technology Stack

### Hardware

| Part | Choice | Why |
| --- | --- | --- |
| MCU board | Waveshare RP2040-Zero | Native USB, 23.5×18mm castellated pads, USB-C, onboard WS2812 RGB LED for toolchain smoke-testing. Chosen over the Seeed XIAO RP2040 — functionally equivalent, edged out by the onboard LED; only firmware difference is pin naming (`GPIO0`-style, not XIAO's `D0`-style). |
| Status LEDs | Custom PCBA, 3x discrete LED bulbs (Red/Yellow/Green), 4-pin connector (`GND`, `Red`, `Yellow`, `Green`) | Each bulb is a simple on/off GPIO output — no timing-sensitive protocol. Current-limiting resistors live on the PCBA itself. Simpler to drive than an addressable strip, at the cost of losing per-pixel/animatable color — an acceptable trade since the product only ever needs 3 fixed colors. |
| Cable / connector | 4-conductor wire or JST-style connector, plus a data-capable USB-C to USB-A cable to the host | 4 wires (`GND`+3 signal) MCU→PCBA; USB-C carries power+serial to the host. |
| Enclosure | 3D-printed or laser-cut diffuser + base | Never built — this variant was put on hold before reaching enclosure design. |

### Firmware

- **Language:** C++ (Arduino framework).
- **Library:** none — 3 discrete bulbs driven with plain `digitalWrite`/`analogWrite`, no NeoPixel/FastLED dependency.
- **Toolchain:** Arduino IDE (or Arduino CLI) with the `arduino-pico` board package.
- **Interface:** USB CDC serial — enumerates as a plain serial port on every OS.

### Host Driver Software

- **Language:** Python 3 — runs identically on Linux/Windows/macOS with minimal setup.
- **Key library:** `pyserial`.
- **Packaging:** pip-installable package (`andon-light`) exposing a CLI.
- **Integration point:** Claude Code [Hooks](https://docs.claude.com/) — `SessionStart` → idle, `UserPromptSubmit`/`PreToolUse` → working, `Notification`/`PermissionRequest` → waiting, `PreCompact` → compacting, `Stop` → idle. Commands run synchronously, not `async` — see [`../../../hooks/README.md`](../../../hooks/README.md) "Why not async."
- **Known gap:** no hook fires on a user-initiated Esc/interrupt — not exposed by Claude Code's hook system at the time. The light holds its last color through an Esc interrupt.

---

## 2. Architecture

```txt
┌─────────────────────────┐
│  Claude Code / CLI agent│
│  (hooks fire on events) │
└───────────┬─────────────┘
            │ shell exec
            ▼
┌───────────────────────────┐
│  andon-light CLI (Python) │  ← host/
└───────────┬───────────────┘
            │ USB CDC serial (simple text protocol)
            ▼
┌───────────────────────────┐
│  Firmware (C++/Arduino)   │  ← firmware/
│  - parses commands        │
│  - drives 3 discrete LEDs │
│  - watchdog / auto-idle   │
└───────────┬───────────────┘
            │ 3 GPIO pins (+ shared GND)
            ▼
┌───────────────────────────┐
│  Custom PCBA, 3x LED bulbs│
│  Green / Yellow / Red     │
└───────────────────────────┘
```

**Wire protocol:**

| Command | Effect |
| --- | --- |
| `G\n` | Solid green (agent working) |
| `Y\n` | Solid yellow (waiting for human input / permission) |
| `R\n` | Solid red (idle / stopped / quota reached) |
| `C\n` | Flashing green (compacting — internal maintenance, still alive) |
| `H\n` | Heartbeat — no color change, resets watchdog |

`C` (flashing green, `kFlashPeriodMs = 500`) is a sharp on/off blink, visually distinct from `StalePulse`'s slow smooth breathing fade — a user glancing at the light can tell "busy with maintenance" from "may be disconnected" at a glance.

**Reliability:** the firmware runs a watchdog timer — no heartbeat/command within **30 minutes** falls back to a slow-pulse red ("stale/disconnected") rather than silently freezing on a stale color if the host driver crashes. See History for how the timeout was tuned.

---

## 3. Roadmap

| # | Goal | Status |
| --- | --- | --- |
| 0 | Research & order parts | Done |
| 1 | Breadboard MVP (firmware only) | Done |
| 2 | Host CLI MVP | Done |
| 3 | Claude Code hook integration | Done |
| 4 | Reliability pass | Mostly done — live unplug/replug + long-turn stress test never completed |
| 5 | Custom PCB | On hold, then superseded — the strip variant went first and became the sole ongoing hardware line |
| 6 | Enclosure | Not started (blocked on Phase 5) |
| 7 | Packaging & distribution | Not started for this variant — superseded by the strip variant's own Phase 7 |
| 8 | Stretch goals | Backlog, not pursued |

---

## 4. History

| Date | Event |
| --- | --- |
| 2026-07-05 | Kickoff. MCU decision: Waveshare RP2040-Zero over Seeed XIAO RP2040. |
| 2026-07-07 | Breadboard MVP (Phase 1) flashed and confirmed: `G`/`Y`/`R` correct on physical bulbs, watchdog stale-pulse confirmed. Host CLI MVP (Phase 2) done: `andon-light doctor` auto-detected the board (`DEFAULT_VID = 0x2E8A`, confirmed via `udevadm`); `set working/waiting/idle` confirmed end-to-end. Hook integration (Phase 3) done: merged into `~/.claude/settings.json`; hook set expanded to 7 events including `PermissionRequest` and the new `PreCompact`→flashing-green mapping; `async` removed after an ordering-race bug. Reliability pass: hardened error handling (clean messages + exit 1 instead of raw traceback), added retry-on-busy-port logic. Watchdog timeout raised from an initial 15s to 30 minutes after real sessions showed false stale-triggers during long tool-call-free thinking stretches; `PreToolUse` hook added to keep the watchdog fed during tool-heavy stretches. |
| 2026-07-08 | Cross-platform one-click installer + permission-gated hooks merge added to scope (was in the original brief, not previously scheduled). |
| 2026-07-11 | Phase 5 (custom PCB) put on hold — the addressable-strip variant was chosen to go first for a custom PCB, since it reached a fully-validated state before this variant's own Phase 5 was picked up. This variant was later fully superseded: the strip became the project's sole ongoing hardware line, and this MVP was archived. |

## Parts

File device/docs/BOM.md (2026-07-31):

# Bill of Materials: Agent Andon Light

Every part is a standard, unrestricted commodity component (MCU dev board + addressable LEDs + passives). Nothing here is export-controlled, encryption-related, or radio-emitting beyond the board's native USB.

## Fabricated PCB (current build)

| Designator | Part | Qty | Footprint |
| --- | --- | --- | --- |
| WS-RP2040-Zero1 | Waveshare RP2040-Zero | 1 | hand-soldered directly to board |
| D1–D10 | WS2812B-2020 addressable RGB LED | 10 | WS2812B-2020 |
| C1 | 470 µF electrolytic capacitor | 1 | CP_Elec 6.3×5.4 |
| C2–C11 | 100 nF ceramic capacitor (one per LED) | 10 | 0402 |
| R1 | 330 Ω resistor, series on data line | 1 | 0805 |

No level-shifter footprint populated — unnecessary at 3.3V logic for this LED batch. Full sourcing detail (LCSC part numbers, manufacturer, datasheet links) is in [`andon_light_strip-RevA-BOM.csv`](../hardware/manufacturing/pcba/send-to-jlc/andon_light_strip-RevA-BOM.csv) and its CPL file — generated straight from KiCad, authoritative over this table if they ever disagree.

**Enclosure:** 3D-printed chassis, base + lid. STEP files: [`chassis_base`](../hardware/models/andon_light_chassis_base.step), [`chassis_lid`](../hardware/models/andon_light_chassis_lid.step).

## Breadboard / hand-wired build

For prototyping without the fabricated PCB:

| # | Part | Qty | Notes |
| --- | --- | --- | --- |
| 1 | Waveshare RP2040-Zero | 1 | — |
| 2 | Custom PCBA, WS2812-style addressable strip (10 LEDs) | 1 | — |
| 3 | Half-size breadboard | 1 | — |
| 4 | Jumper wire set (M-M, M-F) | 1 set | — |
| 5 | 3-pin connector matching the PCBA's header (`S`/`V`/`G`) | 1 | Match the PCBA's header type (JST or pin header) |
| 6 | USB-C to USB-A cable, data-capable | 1 | Many cheap cables are charge-only and won't enumerate as serial |
| 7 | 74HCT125 level shifter (optional) | 1 | Only if data-line glitches appear — see [`TROUBLESHOOTING.md`](TROUBLESHOOTING.md) Step 3.5 |
| 8 | 330–470 Ω resistor (optional, recommended) | 1 | Series on data line (`GPIO1` → strip `S`), close to strip end |
| 9 | Electrolytic capacitor, 100–1000 µF ≥6.3V (optional, recommended) | 1 | Across `V`/`G`, close to strip end. Polarized. |

No soldering required beyond the MCU's header pins — everything else plugs together.

## Notes

- Assembly-service SMD placement requires the listed parts to be in that assembler's own stock — check before finalizing the KiCad BOM. Hand-soldering has no such constraint.
- Buy a spare strip PCBA if redesigning — cheap insurance against a dead LED or reversed-polarity mistake.
- An earlier iteration used a different LED board — 3 discrete bulbs (Red/Yellow/Green) on a 4-pin connector. Preserved for reference at [`../../archive/led-bulb-mvp/docs/BOM.md`](../../archive/led-bulb-mvp/docs/BOM.md); not part of the current build.

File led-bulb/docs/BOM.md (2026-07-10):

# Bill of Materials: Agent Andon Light

Two BOMs: **Phase 1 (breadboard MVP)** — buy this first, cheap, to prove the whole concept — and **Phase 2 (custom PCB)**, once the software/firmware works end-to-end.

Every part below is a standard, unrestricted commodity electronic component (microcontroller dev board + addressable LEDs + passives). Nothing here is export-controlled, encryption-related, or radio-emitting beyond the board's native USB.

## Phase 1 — Breadboard MVP

| # | Part | Qty | Approx. Cost | Notes |
| --- | --- | --- | --- | --- |
| 1 | Waveshare RP2040-Zero | 1 | ¥30 | The MCU dev board — see `Implementation-Summary.md` §1 for why this board was chosen |
| 2 | Custom PCBA, 3x LED bulbs (Red/Yellow/Green) | 1 | — (already in hand) | — |
| 3 | Half-size breadboard | 1 | ¥10 | — |
| 4 | Jumper wire set (M-M, M-F) | 1 set | ¥10 | — |
| 5 | 4-pin connector/wire matching the PCBA's header (GND, R, Y, G) | 1 | ¥5 | Match the PCBA's actual header type (JST or plain pin header) |
| 6 | USB-C to USB-A cable (data-capable) | 1 | ¥15 | Confirm it's rated for data transfer, not charge-only — many cheap cables are power-only and won't enumerate as a serial device |

**Phase 1 total: ~¥60 (~$8), plus whatever the PCBA itself cost.** No soldering strictly required beyond the MCU's header pins — everything else plugs together.

> **Note (2026-07-07):** the LED side of Phase 1 changed from a WS2812B addressable strip to a custom PCBA with 3 discrete LED bulbs (Red/Yellow/Green) on a 4-pin connector (`GND`+3 signal) — already in hand, so it's no longer a line item to source. This also drops the WS2812-specific parts (data-line resistor, decoupling cap, level shifter) from both phases below, since discrete on/off LEDs don't need them — any current-limiting resistors live on the PCBA itself.

## Phase 2 — Custom PCB

Adds to / replaces Phase 1 parts once the design is finalized in KiCad.

| # | Part | Qty | Approx. Cost | Notes |
| --- | --- | --- | --- | --- |
| 1 | Waveshare RP2040-Zero | 1 | ¥30 | Same module, now hand-soldered onto the custom PCB via its castellated edge pads |
| 2 | LED bulbs (Red/Yellow/Green, 5mm through-hole or SMD to match final footprint) | 3 | ¥3 | Same 3 discrete colors as the Phase 1 PCBA, sourced individually if integrating them onto a new board rather than reusing the existing PCBA |
| 3 | 220–330 Ω resistor x3 (one per LED, through-hole or 0805 SMD to match) | 3 | ¥1 | Current-limiting per bulb — simple Ohm's-law sizing for a plain on/off LED, no protocol timing concerns like WS2812 had |
| 4 | USB-C connector (if not relying on the RP2040-Zero's onboard port) | 1 | ¥2 | Only needed if the enclosure design routes the cable differently than the board's own port |
| 5 | Custom PCB (2-layer), CAD sent to a fab | 5–10 (min order) | ¥15–35 total | Order 5–10 minimum — spares are nearly free at this size |
| 6 | 3D-printed or laser-cut enclosure/diffuser | 1 set | ¥10–35 | Can ride along with the PCB order (many fabs offer this as an add-on) or be sourced separately |

**Phase 2 total: ~¥50–90** including PCB fab minimums and enclosure (spread across however many units you order — 5–10 boards for the price of one is normal for small-batch PCB fab, so keep the spares). If Phase 2 just reuses the existing 3-bulb PCBA from Phase 1 rather than redesigning the LED board, items #2–3 aren't needed at all — only relevant if consolidating everything (MCU + LEDs) onto one new board.

## Notes

- If you want an assembly service to place and solder the SMD parts for you rather than hand-soldering, the parts you list in the BOM need to be in that assembler's own stock — check before finalizing the KiCad BOM. Hand-soldering has no such constraint.
- Buy a spare LED bulb or two of each color if redesigning the LED board in Phase 2 — cheap insurance against a dead LED or a reversed-polarity mistake during hand-soldering.

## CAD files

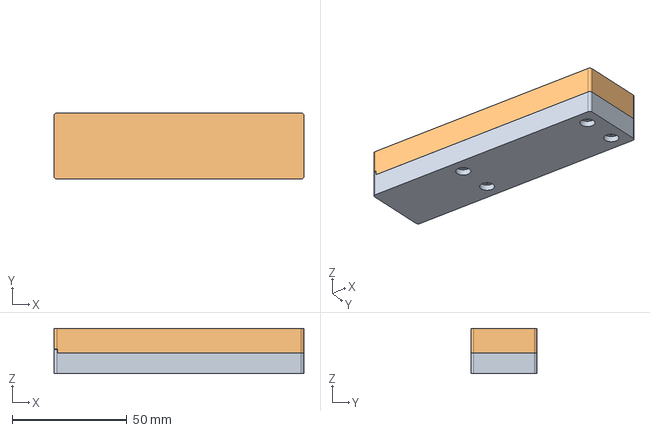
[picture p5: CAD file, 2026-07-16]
device/hardware/cad/andon_light_chassis.FCStd
109.0 x 28.8 x 19.7 mm
Andon Light Chassis Base
Andon Light Chassis Lid

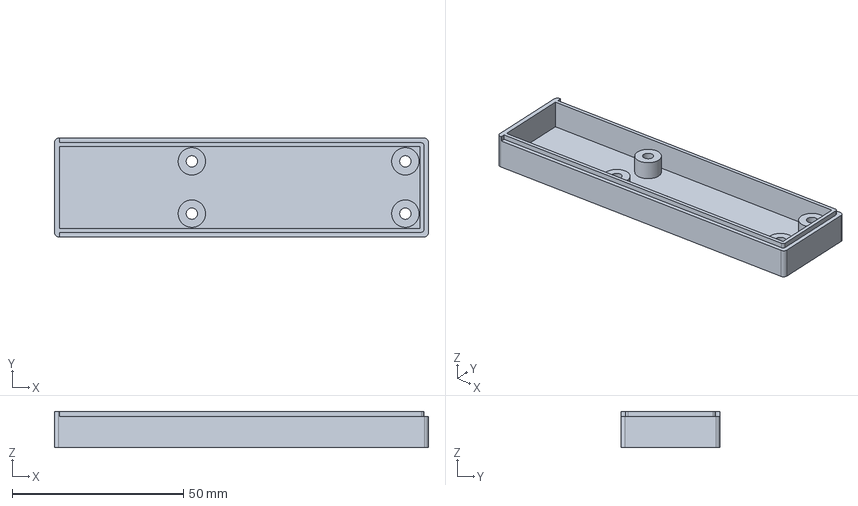
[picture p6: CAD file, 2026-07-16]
device/hardware/models/andon_light_chassis_base.step
109.0 x 28.8 x 10.5 mm

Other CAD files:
device/hardware/models/andon_light_chassis_lid.step
device/hardware/cad/andon_light_chassis_lid.stl

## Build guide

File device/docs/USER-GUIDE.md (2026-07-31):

# User Guide: Agent Andon Light

Building and running the hardware, start to finish. Parts list: [`BOM.md`](BOM.md).

## Contents

- [User Guide: Agent Andon Light](#user-guide-agent-andon-light)
  - [Contents](#contents)
  - [1. Software Setup](#1-software-setup)
  - [2. Build the Hardware](#2-build-the-hardware)
    - [2a. Fabricated PCB](#2a-fabricated-pcb)
    - [2b. Breadboard Prototype (Optional)](#2b-breadboard-prototype-optional)
  - [3. Flash \& Verify](#3-flash--verify)
  - [Reference](#reference)
    - [Glossary](#glossary)
    - [Pixel Layout](#pixel-layout)
    - [Pitfalls to Avoid](#pitfalls-to-avoid)
    - [OS-Specific Notes](#os-specific-notes)
    - [Wire Protocol Reference](#wire-protocol-reference)

## 1. Software Setup

1. Install the Arduino IDE (2.x).
2. Add the RP2040 board package:
   - Arduino IDE → Preferences → "Additional Board Manager URLs" → add the `arduino-pico` URL.
   - Boards Manager → install "Raspberry Pi Pico/RP2040."
   - Select **"Waveshare RP2040-Zero"** as the board when flashing.
3. Install the NeoPixel library — Tools → Manage Libraries → search "Adafruit NeoPixel" → Install.

## 2. Build the Hardware

Pick the section that matches what you have — do one, not both.

### 2a. Fabricated PCB

Start here if you have the fabricated PCB. The fab's assembly service already placed the LEDs and passives; the RP2040-Zero is the one part you solder on yourself.

The fabricated PCB is a single board — MCU and LED strip together, not two boards joined by wires.

1. Solder the RP2040-Zero's castellated edge pads directly onto the board's matching pads. Solder every pad — the ones carrying signal/power connect the MCU to the board's traces, and any unused ones are purely mechanical.

```txt
   top of board
        |
        v
   ______________
  |              |
  |   PCB body   |___
  |  (green)     |   \___ castellated half-hole
  |______________|       (plated copper inside)
        |
        | <- solder fills the gap between the MCU's
        |    pad and the board's matching pad
        v
     ( o )  <- solder joint
```

**Caution:** let each joint cool a few seconds before touching it, and never bridge two adjacent pads with one solder blob.

That's the whole build — no connector, no cable, no wiring step. The `GPIO1` (`kDataPin`) trace between MCU and LEDs is etched into the PCB itself, fixed by the board layout. Continue to [3. Flash & Verify](#3-flash--verify).

### 2b. Breadboard Prototype (Optional)

Skip this if you have the fabricated PCB — you're already done above. This path validates the firmware against a standalone RP2040-Zero dev board wired by hand to a separate LED strip PCBA — the setup used during development before the custom PCB existed.

1. **Solder header pins onto the RP2040-Zero.** It ships bare — the edge holes are castellated pads, not header pins. Solder at least **5V**, **GND**, and one **GPIO** pin (firmware default `GPIO1`). A male header strip (recommended) lets it plug into a breadboard like any module; soldering wires directly works too but hard-wires it to those specific wires. Let each joint cool before touching it, and never bridge two adjacent pads with one solder blob.

2. **Wire it to the LED strip PCBA:**

   ```txt
    [RP2040-Zero]                    [LED Strip PCBA, 3-pin connector]
      GND o---------------------------o G  (ground)
      5V  o---------------------------o V  (power — NOT 3V3, see below)
      GP1 o---------------------------o S  (signal/data)

      USB-C port -----> cable -----> your computer
   ```

   - Seat the MCU on a breadboard, if you have one.
   - Connect `G` (ground) first.
   - Connect `V` to `5V`/`VBUS`, not `3V3` — 10 addressable LEDs draw more current than `3V3` is meant to supply.
   - Connect `S` to a free GPIO pin, matching `kDataPin` in `andon_light_firmware.ino` (or edit the sketch to match your wiring).
   - Plug in USB-C last, once all 3 wires are connected — powering a half-wired setup risks a short.
   - Optional resistor/capacitor: see [`BOM.md`](BOM.md) items #8–9.

Continue to [3. Flash & Verify](#3-flash--verify).

## 3. Flash & Verify

1. Open `device/firmware/andon_light_firmware/andon_light_firmware.ino` in the Arduino IDE.
2. Select **"Waveshare RP2040-Zero"** as the board, then flash.
3. Open the Serial Monitor (115200 baud, line ending "Newline").
4. Confirm pixel 1 alone lights dim white on boot, and pixels 2-10 are dark.
5. Send `G`, `Y`, `R` — confirm each lights only its own 3-pixel section (2-4 / 5-7 / 8-10), not the whole strip.

You now have a working device. Next: install the host CLI and Claude Code hooks — see the top-level [`README.md`](../../README.md) Quick Start.

## Reference

### Glossary

| Term | Meaning |
| --- | --- |
| MCU (microcontroller) | The chip on your dev board that runs the firmware. On the RP2040-Zero, that's the RP2040. |
| Firmware | The program running *on* the MCU, not on your laptop. Written in C++ (Arduino framework). |
| Dev board | A ready-made PCB with the MCU plus USB and power regulation already wired up. The RP2040-Zero is one. |
| Addressable LED / WS2812 | An LED controlled over a single data wire via a precisely-timed protocol. Many can be daisy-chained on one wire, each set to its own color individually. |
| NeoPixel | Adafruit's name for WS2812-family LEDs, and the Arduino library (`Adafruit_NeoPixel`) that drives them. |
| Data line / signal timing | WS2812 LEDs read color from a sequence of ~800kHz timed pulses — too fast/precise for plain `digitalWrite`, hence the NeoPixel library. |
| Serial / USB CDC | The dev board shows up as a plain serial port over USB, so Python can read/write it directly. No custom driver needed on any OS. |
| Watchdog | A firmware safety timer that resets to a known-safe state if it hasn't heard from the host in too long. |
| KiCad | Free, open-source PCB design software — see [`../hardware/`](../hardware/). |
| PCBA | "PCB Assembly": a bare PCB with all components soldered on. |

### Pixel Layout

| Pixels | Section | Lit by |
| --- | --- | --- |
| 1 | Status | Always on (dim white) |
| 2–4 | Green | `G` |
| 5–7 | Yellow | `Y` |
| 8–10 | Red | `R` / stale-pulse |

| State | Behavior |
| --- | --- |
| `G` (working) | Pixels 2-4 solid green |
| `Y` (waiting) | Pixels 5-7 solid yellow |
| `R` (idle) | Pixels 8-10 solid red |
| Stale (watchdog timeout) | Pixels 8-10 breathe red |
| `C` (compacting) | Chase-fill: pixels light one at a time from pixel 10 down to pixel 2, each pass locking one more pixel starting from pixel 2 upward, until all 9 are lit — then it resets and repeats |

Pixel 1 stays dim white through every state, including right after boot.

If all 10 pixels light the same color at once, that's pre-refinement firmware — reflash from the current `device/firmware/` source.

### Pitfalls to Avoid

| Pitfall | What to know |
| --- | --- |
| `V` wired to `3V3` instead of `5V` | Breadboard build only. The most common wiring mistake — 10 addressable LEDs need the extra current headroom. |
| Flicker or wrong colors on power-up | Usually a data-line signal integrity issue, not a firmware bug. **Fabricated PCB:** check for a cold solder joint on the MCU's pads. **Breadboard:** see the level-shifter fallback in [`TROUBLESHOOTING.md`](TROUBLESHOOTING.md) Step 3.5. |
| Wrong connector pinout | Breadboard build only. Read the PCBA's silkscreen labels directly — don't assume pin order from this doc or a photo. |
| Charge-only USB-C cable | Board won't enumerate as a serial port. Try a different cable first. |
| Skipping the Serial Monitor check | It isolates firmware bugs from host-CLI bugs before you add the Python CLI on top. |
| Hooks not resetting the watchdog | Claude Code hooks fire only at discrete moments, not continuously — a long thinking-only stretch with no tool calls can leave the watchdog unfed. `PreToolUse` resets it on every tool call. |

Heartbeat/watchdog isn't optional polish — it's what makes this device trustworthy to walk away from.

### OS-Specific Notes

| OS | CDC driver behavior |
| --- | --- |
| Windows | Enumerates as a COM port with no extra driver install. |
| Linux | Enumerates as `/dev/ttyACM0`; your user needs `dialout` group membership — see [`TROUBLESHOOTING.md`](TROUBLESHOOTING.md). |

### Wire Protocol Reference

| Command | Effect | Meaning |
| --- | --- | --- |
| `G\n` | Solid green | Agent working |
| `Y\n` | Solid yellow | Waiting for human input / permission |
| `R\n` | Solid red | Idle / stopped / session start |
| `C\n` | Flashing green | Compacting (internal maintenance, still alive) |
| `H\n` | No color change | Heartbeat, resets the watchdog |

Watchdog timeout: **30 minutes**.

Hook mapping (rationale: [`../../hooks/README.md`](../../hooks/README.md)):

| Hook event | Color |
| --- | --- |
| `SessionStart` | idle |
| `UserPromptSubmit` / `PreToolUse` | working |
| `Notification` / `PermissionRequest` | waiting |
| `PreCompact` | compacting |
| `Stop` / `SessionEnd` | idle |

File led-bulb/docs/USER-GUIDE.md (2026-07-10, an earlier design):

# User Guide & Reminders: Agent Andon Light

A companion doc for the "I've never built hardware before" part of this project — terminology, setup steps, and pitfalls to remember. Covers the **3-discrete-bulb variant** — for the addressable LED strip variant, see `../../led-strip/docs/USER-GUIDE.md`. See `Implementation-Summary.md` for the architecture/roadmap, and `BOM.md` for parts.

## Glossary (hardware terms used across this project)

- **MCU (microcontroller)** — the small computer chip on your dev board. The Waveshare RP2040-Zero has one (the RP2040 chip itself). It runs the firmware you write.
- **Firmware** — the program that runs *on* the MCU, as opposed to on your laptop. Written in C++ here, using the Arduino framework.
- **Dev board** — a small ready-made PCB with the MCU plus USB, power regulation, etc. already wired up, so you don't need to design that part yourself. The RP2040-Zero is a dev board.
- **Discrete LED** — a plain single-color LED bulb, as opposed to an addressable RGB LED — you turn it on/off (or dim it) with a normal GPIO pin, no special protocol or library needed. This project uses 3 of them (Red/Yellow/Green) on a custom PCBA instead of an addressable strip.
- **Serial / USB CDC** — a way for the dev board to show up on your computer as a plain "serial port" (like an old-school COM port) over USB, so your Python code can just open it and write/read text, no custom USB driver needed on Linux/macOS.
- **Watchdog** — a safety timer in the firmware that resets to a known-safe state if it doesn't hear from the host software for too long, so the device fails safely instead of freezing on stale data.
- **KiCad** — free, open-source software for designing PCBs (used in Phase 2, not needed for Phase 1's breadboard).
- **PCBA** — "PCB Assembly": a bare PCB with all the components soldered onto it. A PCB fab/assembly service can do this for you from your KiCad files, or you can hand-solder it yourself. You already have one for the 3 status LEDs.

## Phase 1 Setup Checklist (Breadboard MVP)

1. Install the Arduino IDE (2.x).
2. In Arduino IDE → Preferences → "Additional Board Manager URLs", add the `arduino-pico` board package URL, then install "Raspberry Pi Pico/RP2040" boards via the Boards Manager — select "Waveshare RP2040-Zero" as the board when flashing. No LED library needed — the 3 bulbs are driven with plain `digitalWrite`/`analogWrite`.
3. Wire the PCBA (see "Soldering Pins First" and "Wiring the LED PCBA" below for the full walkthrough if this is your first time): PCBA `GND` → board `GND`, PCBA `Red`/`Yellow`/`Green` → 3 board GPIO pins of your choice (note them in the sketch — the firmware defaults to `GPIO1`/`GPIO2`/`GPIO3`, placeholders to confirm against your actual wiring).
4. Flash a simple test sketch that cycles red → yellow → green every 2 seconds. If this works, your hardware is good and everything else is software from here.
5. Open the Arduino Serial Monitor, send `G`, `Y`, `R` as single characters, and confirm the LED responds — this is your firmware's command parser working before Python ever gets involved.

## Soldering Pins First

The Waveshare RP2040-Zero ships **bare** — the holes along its edges are **castellated pads** (plated half-holes), not header pins. Nothing plugs into a breadboard until something is soldered into them. This step comes before any breadboard wiring.

Board edge, cross-section of one pad:

```txt
   top of board
        |
        v
   ______________
  |              |
  |   PCB body   |___
  |  (green)     |   \___ castellated half-hole
  |______________|       (plated copper inside)
        |
        | <- header pin inserted through the hole,
        |    then soldered so solder fills the gap
        v
     ( o )  <- solder joint (shiny blob once cooled)
```

Solder at least: **5V**, **GND**, and one **GPIO** pin (the firmware defaults to `GP0`). Read the actual label printed on your board next to each pad — don't guess positions from any diagram, including this one.

Two ways to do it:

- **Solder a male header strip into the pads (recommended).** Once cooled, the board plugs straight into a breadboard like any other module — reusable for future revisions.
- **Solder wires directly into the pads.** Works with no header stock on hand, but that board is now hard-wired to those specific wires — less flexible if you re-wire later.

**Caution:** let the board cool a few seconds after each joint before touching it, and solder 5V and GND on separate pins — never bridge two adjacent pads with one solder blob.

## Wiring the LED PCBA

Much simpler than an addressable strip — 4 wires total, no resistor or capacitor to add (they're already on the PCBA), no shared power rail needed since each LED just needs its own GPIO plus a common ground.

**Reading your boards:** both the RP2040-Zero and the LED PCBA have their pin/pad names printed directly on the silkscreen (tiny white text — `GND`, `GP1`, `Red`, `Green`, etc). Read the actual text on your physical boards rather than matching positions from a photo/tutorial — exact pin placement isn't something to guess at, and the firmware's default pin numbers (`GPIO1`/`GPIO2`/`GPIO3`) are placeholders until you confirm them.

```txt
 [RP2040-Zero]                    [LED PCBA, 4-pin connector]
   GND o---------------------------o GND
   GP1 o---------------------------o Green
   GP2 o---------------------------o Yellow
   GP3 o---------------------------o Red

   USB-C port -----> cable -----> your computer
```

1. **Seat/steady the MCU** on a breadboard if you have one handy — not required electrically, just makes it easier to hold still while wiring.
2. **Connect `GND` first.** One wire from the MCU's `GND` pin to the PCBA's `GND` pin — every other wire's signal is measured relative to this, so get it in before anything else.
3. **Connect the 3 signal wires**, one MCU GPIO pin each to the PCBA's `Red`/`Yellow`/`Green` pins. Any 3 free GPIO pins work — just make sure the pin numbers you wired match `kGreenPin`/`kYellowPin`/`kRedPin` in `andon_light_firmware.ino` (or edit the sketch to match your wiring, whichever's easier).
4. **Plug in USB-C last**, once all 4 wires are connected — powering a half-wired setup risks a short.

## Reminders / Pitfalls

- **Confirm the connector pinout before plugging in.** Don't assume pin order from this doc or a photo — read the PCBA's silkscreen labels directly, and double check `GND` isn't accidentally landed on a signal pin (or vice versa) before powering on.
- **Data-capable cable, always.** Many USB-C cables are charge-only. If the board doesn't enumerate as a serial port on your computer, try a different cable before debugging code.
- **Don't skip the Serial Monitor step** (Phase 1, step 6) even though it feels redundant with building the Python CLI next — it isolates firmware bugs from host-software bugs, which matters a lot the first time you're debugging both halves of a system you've never built before.
- **Windows CDC driver:** if the board doesn't show up in Device Manager as a COM port, the `arduino-pico` package usually installs the right driver automatically; if not, that's the first thing to search for by exact board name + "Windows driver".
- **Heartbeat/watchdog isn't optional polish** — it's what makes this device trustworthy to walk away from. Don't defer it past Phase 4 in practice even if the roadmap lists it later; a status light that can silently go stale is worse than no status light.
- **Claude Code hooks only fire at discrete moments, not continuously.** Real-world testing (2026-07-07) showed the light falsely dropping to the stale-pulse mid-turn, because nothing resets the watchdog during a long stretch of the model just thinking with no tool calls in between hook events. Fixed by adding a `PreToolUse` hook (kicks the watchdog on every tool call) and raising the watchdog timeout from 15s to 30 minutes — see `../firmware/README.md` and `../../hooks/README.md`.

## Quick Reference: Wire Protocol (v1)

```text
G\n   solid green    → agent working
Y\n   solid yellow   → waiting for human input / permission
R\n   solid red      → idle / stopped / quota reached / default at session start
C\n   flashing green → compacting (internal maintenance, still alive)
H\n   heartbeat      → no color change, resets the watchdog timer
```

Watchdog timeout: **30 minutes** (raised from an initial 15s once real Claude Code sessions showed long thinking-only stretches falsely triggering the stale state).

Hook mapping (fine-tuned 2026-07-07 from real usage — see `../../hooks/README.md`): `SessionStart`→idle, `UserPromptSubmit`/`PreToolUse`→working, `Notification`/`PermissionRequest`→waiting, `PostCompact`→compacting, `Stop`→idle.

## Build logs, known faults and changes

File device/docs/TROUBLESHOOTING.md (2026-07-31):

# Troubleshooting: Agent Andon Light

Diagnostic playbook — work through these in order to narrow down where a problem actually is. Copy-paste each command into a terminal; read the table below it before running, so you know what to look for.

## Start Here

| Symptom | Go to |
| --- | --- |
| Light completely dark / unresponsive | [Step 1](#step-1-is-the-board-running-firmware) |
| Colors wrong/flickery, or the lit section itself looks broken | [Step 3.5](#step-35-flicker-wrong-colors-or-unexpected-partial-lighting) |
| Light on but wrong color, or stuck | [Step 4](#step-4-is-the-hook-config-correct) |
| `andon-light` command fails or errors | [Step 2](#step-2-is-the-device-reachable-by-the-host-cli) |
| Worked once, broke after unplug/replug | [Step 1](#step-1-is-the-board-running-firmware) |

## Step 1: Is the Board Running Firmware?

```txt
lsusb | grep -i "2e8a"
```

| Output | Meaning | Fix |
| --- | --- | --- |
| `2e8a:0003 Raspberry Pi RP2 Boot` | Board is in **bootloader mode**, not running firmware — no LEDs will respond, no serial port exists | Open Arduino IDE and click Upload — it detects this state and finishes the flash |
| Line with `Waveshare` or `RP2040 Zero` | Firmware **is** running normally | Move to Step 2 |
| Nothing | Board not connected, or cable isn't data-capable | Try a different USB-C cable, confirm it's fully seated |

You can also check for the bootloader's mass-storage drive directly:

```txt
find /media /run/media /mnt -maxdepth 3 -iname "*RPI*" 2>/dev/null
```

A printed path (e.g. `/run/media/sean/RPI-RP2`) confirms bootloader mode — same fix as above.

## Step 2: Is the Device Reachable by the Host CLI?

```txt
andon-light doctor
```

| Output | Meaning |
| --- | --- |
| `Found device on /dev/ttyACM0` (or similar) | CLI can see it, port permissions are fine — move to Step 3 |
| `No device found` | Board isn't running firmware — go back to Step 1 |
| `[Errno 13] Permission denied` | Port-permissions issue — see [Linux-Specific: Permission Denied](#permission-denied-opening-the-port) below |

## Step 3: Is Something Else Holding the Port Open?

```txt
andon-light set idle
```

| Output | Meaning |
| --- | --- |
| Succeeds silently, exit code 0 | CLI → firmware link works. LEDs didn't change? Go to Step 3.5, or reflash (Step 1). |
| `andon-light: serial error: ... Device or resource busy` | Another program has the port open — almost always Arduino IDE's Serial Monitor. Close it and retry. |

Check the exit code explicitly if the message scrolled past:

```txt
andon-light set idle; echo "exit code: $?"
```

## Step 3.5: Flicker, Wrong Colors, or Unexpected Partial Lighting

Addressable strips depend on precise data timing and adequate power, not just an on/off signal.

**Rule out the obvious non-bug first:** partial lighting is the design, not a fault. `G`/`Y`/`R` each light only their own 3-pixel section (2-4 / 5-7 / 8-10) plus the always-on status pixel (1) — see [`USER-GUIDE.md`](USER-GUIDE.md) Pixel Layout. Seeing 7 pixels dark while `G` is active is correct. The problems below look different: pixels *within* the active section are wrong, or the pattern doesn't match any valid section at all.

On the **fabricated PCB**, MCU and LEDs share one board — there's no wire or connector to inspect, so "signal integrity" problems are almost always a bad solder joint. On the **breadboard build**, the same symptoms are usually the jumper wiring instead. Both are covered below.

| Symptom | Likely cause | Fix |
| --- | --- | --- |
| Some pixels in the active section are garbled/dark, others correct | Data-line signal integrity — the RP2040 drives the data line at 3.3V logic; a marginal connection can lose sync partway down the chain | **Fabricated PCB:** check for a cold/bad solder joint on the MCU's pads. **Breadboard:** shorten the `S` wire, check the connector crimp, or add a 74HCT125 level shifter (see [`BOM.md`](BOM.md) item #7) |
| Dim colors, wrong hue, or the board browns-out/resets when the light comes on | Insufficient 5V supply to the LEDs | **Fabricated PCB:** check the USB-C cable is data *and* power capable, and the solder joints on the power pads. **Breadboard:** confirm `V` is wired to `5V`/`VBUS`, not `3V3` — see [`USER-GUIDE.md`](USER-GUIDE.md) Pitfalls to Avoid |
| Nothing lights at all — not even pixel 1 — but `andon-light set idle` returns exit code 0 | `kDataPin` in `andon_light_firmware.ino` doesn't match the actual data pin | **Fabricated PCB:** confirm `kDataPin` still matches the board's designed trace (`GPIO1` by default — don't edit this unless you changed the PCB design). **Breadboard:** check the pin you wired against `kDataPin`. Either way, this is the pin, not the LEDs — if pixel 1 lights but sections 2-10 stay dark regardless of command, that's Step 3, not this. |
| Lit pixels don't line up with the expected sections (e.g. `G` lights pixels 4-6 instead of 2-4) | The strip's data-in end doesn't match the firmware's assumption | **Fabricated PCB:** this would mean a fab/design defect — check against a known-good unit before assuming it's yours. **Breadboard:** check which end of the strip PCBA is silkscreened as the data input, confirm `S` is wired there |

Still stuck? Confirm the Adafruit_NeoPixel library is actually installed (Arduino IDE → Tools → Manage Libraries → search "Adafruit NeoPixel") — a missing library shows as a compile error, not a runtime symptom, but worth ruling out.

## Step 4: Is the Hook Config Correct?

```txt
cat ~/.claude/settings.json
```

- [ ] **Valid JSON?** Run:

  ```txt
  python3 -c "import json, os; json.load(open(os.path.expanduser('~/.claude/settings.json'))); print('VALID JSON')"
  ```

  If this errors, the file has a syntax mistake (usually a missing comma or brace) — Claude Code will likely ignore the whole `hooks` block until it's fixed.
- [ ] **Does every hook command end in `|| true`?** Without it, a hook failure (e.g. device unplugged, or the permission error above) surfaces as noisy error output in Claude Code instead of failing silently. This also means Claude Code's own hook log can say "completed successfully" even when the underlying `andon-light` call actually failed — don't trust that log line as proof the light changed; run the command directly (without `|| true`) and check its real exit code if you suspect this.
- [ ] **Are hook commands *not* marked `"async": true`?** Async causes hook commands to complete out of order, leaving the light stuck on a stale color — see [`../../hooks/README.md`](../../hooks/README.md) "Why not async."
- [ ] **Did you restart Claude Code after editing this file?** Hook config is only read when a session starts — a session already running won't pick up a config change. This is the single most common "why didn't it do anything" cause.

## Step 5: Manually Simulate What a Hook Would Do

Useful to isolate "is it the light/CLI, or is it Claude Code's hooks" — run the exact commands a hook would run, by hand:

```txt
andon-light set working    # pixels 2-4 solid green (rest dark except pixel 1)
andon-light set waiting    # pixels 5-7 solid yellow (rest dark except pixel 1)
andon-light set idle       # pixels 8-10 solid red (rest dark except pixel 1)
andon-light set compacting # chase-fill across pixels 2-10
```

If all four work correctly by hand but the light doesn't react during an actual Claude Code session, the problem is in the hook config (Step 4) or Claude Code hasn't picked it up yet (restart it) — not the hardware or CLI.

## Linux-Specific

### Permission Denied Opening the Port

```txt
ls -la /dev/ttyACM0
```

Look at the group column — should be `dialout`.

**Check with `id`, not `groups $USER`** — they can disagree, and only `id` reflects what a running process actually has:

```txt
id
```

`id` (no arguments) shows the group list baked into *this shell's* live credentials — what the kernel checks when `andon-light` opens the port. `groups $USER` re-queries the account database fresh each time, regardless of what any running process actually has. A user can show `dialout` under `groups $USER` while every currently-running shell — including a brand-new one — still lacks it under `id`, because group membership is fixed into a process's credentials at wherever its session chain started, and a normal desktop log-out doesn't reliably rebuild that in every environment.

If `id` is missing `dialout`:

| Fix | Scope | Command |
| --- | --- | --- |
| Immediate unblock | Current shell only | `newgrp dialout` |
| Permanent fix | Every process, system-wide (only reliable option — a desktop log-out alone isn't guaranteed to rebuild every process's credentials) | `sudo reboot` |
| One-off stopgap | Resets on every replug | `sudo chmod 666 /dev/ttyACM0` |

### Launching Arduino IDE from a Terminal

The Arduino IDE AppImage can fail to launch with a FUSE-related error (`dlopen(): error loading libfuse.so.2` or `Cannot mount AppImage`). If double-clicking doesn't work, run it from a terminal instead — bypasses the FUSE mount entirely:

```txt
cd ~/Downloads
./arduino-ide_2.3.10_Linux_64bit.AppImage --appimage-extract-and-run
```

(Adjust the filename for your downloaded version.) Takes a few seconds to extract and open; restores your previously open sketch/tabs automatically.

### Reference: What "Normal" Looks Like

```txt
$ lsusb | grep 2e8a
Bus 005 Device 010: ID 2e8a:0003 Raspberry Pi RP2 Boot      # bootloader mode (bad if unexpected)

# When firmware is running normally, lsusb won't show a distinct "RP2 Boot" line —
# check udevadm instead:
$ udevadm info -a -n /dev/ttyACM0 | grep -iE "manufacturer|product"
ATTRS{manufacturer}=="Waveshare"
ATTRS{product}=="RP2040 Zero"

$ andon-light doctor
Found device on /dev/ttyACM0

$ andon-light set working; echo "exit=$?"
exit=0
```

## Windows-Specific

### SmartScreen Warning

Neither `andon-light.exe` nor `andon-light-setup.exe` is code-signed, so Windows shows "Windows protected your PC" the first time either one runs, and some antivirus engines may flag the build outright — a PyInstaller `--onefile` binary's self-extract-to-temp-dir behavior at runtime resembles a malware dropper. Neither means the build is broken.

**Fix:** click "More info," then "Run anyway."

### `andon-light` Not Found After Installing

Open a **new** terminal — PATH changes made by the installer don't apply to a terminal that was already open.

### Uninstall Left a Stale PATH Entry

If the installed version predates the current installer's PATH-cleanup logic, its uninstaller won't remove the `PATH` entry it added. Check manually: System Properties → Environment Variables → `Path` (User) → remove any leftover `AndonLight` entry.

## Why `host/` Doesn't Need to Know About the LED Hardware

`host/andon_light/cli.py` maps each state to a single ASCII character (`COLOR_COMMANDS = {"working": "G", "waiting": "Y", "idle": "R", "compacting": "C"}`) and hands it to `SerialLink.send()`, which writes that byte plus `\n` to whatever serial port `device_discovery.py` found. Nothing in `host/` knows or cares how many LEDs are on the other end, what pins they're wired to, or whether they're addressable — that logic lives entirely in firmware (`led_controller.cpp`), on the far side of the serial link. Device auto-detection (`DEFAULT_VID = 0x2E8A`) matches the Waveshare RP2040-Zero itself, independent of the LED board attached to it.

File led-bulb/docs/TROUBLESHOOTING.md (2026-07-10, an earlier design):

# Troubleshooting: Agent Andon Light

A step-by-step diagnostic playbook — the exact terminal commands used to debug every real issue hit while building this project, so you can self-diagnose without needing help. Run these in order; each one narrows down where the problem actually is before you go guessing.

Copy-paste each command block into a terminal. Read the **What it tells you** line before running, so you know what to look for in the output.

## Step 0: what are you actually seeing?

Jump to the matching section:

- Light is completely dark / unresponsive → [Step 1](#step-1-is-the-board-running-firmware-at-all)
- Light is on but the wrong color, or stuck → [Step 4](#step-4-is-the-hook-config-correct)
- `andon-light` command fails or errors → [Step 2](#step-2-is-the-device-reachable-by-the-host-cli)
- Something worked once but broke after unplugging/replugging → [Step 1](#step-1-is-the-board-running-firmware-at-all)

## Step 1: is the board running firmware at all?

```txt
lsusb | grep -i "2e8a"
```

**What it tells you:** every USB device the computer currently sees from this board's vendor ID.

- `2e8a:0003 Raspberry Pi RP2 Boot` → the board is sitting in **bootloader mode**, not running any firmware. No LEDs will respond, no serial port will exist. This happens if you (or a previous flash attempt) held the BOOT button while plugging in, and the flash never completed. Fix: open Arduino IDE and click Upload — it'll detect the board in this state and finish the flash. See "Launching Arduino IDE" below if it's not open.
- A line with `Waveshare` or `RP2040 Zero` in the description → firmware **is** running normally. Move to Step 2.
- Nothing at all → the board isn't connected, or the cable isn't data-capable. Check the USB-C cable (try a different one — many are charge-only) and that it's fully seated.

You can also check for the bootloader's mass-storage drive directly:

```txt
find /media /run/media /mnt -maxdepth 3 -iname "*RPI*" 2>/dev/null
```

If this prints a path (e.g. `/run/media/sean/RPI-RP2`), that confirms bootloader mode — same fix as above.

## Step 2: is the device reachable by the host CLI?

```txt
andon-light doctor
```

**What it tells you:**

- `Found device on /dev/ttyACM0` (or similar) → CLI can see it, port permissions are fine. Move to Step 3.
- `No device found`, or `andon-light` fails with `[Errno 13] Permission denied` → either the board isn't running firmware (go back to Step 1), or it's a permissions issue — check next:

```txt
ls -la /dev/ttyACM0
```

Look at the group column (should be `dialout`).

**Important: check with `id`, not `groups $USER`.** These can disagree, and only one of them reflects reality for a running process:

```txt
id
```

`id` (no arguments) shows the group list actually baked into *this shell's* live credentials — this is what the kernel checks when `andon-light` tries to open the port. `groups $USER` instead re-queries the account database fresh, every time, regardless of what any running process actually has. A user can be correctly listed in `dialout` by `groups $USER` while every currently-running shell (including a brand new one) still lacks it in `id` — group membership is fixed into a process's credentials wherever its session chain started, and a normal desktop **"log out"** does not reliably rebuild that in every environment. This was confirmed the hard way (2026-07-08): even a full logout via the desktop menu, followed by opening a brand-new terminal, still showed no `dialout` in `id` for the new shell.

If `id` is missing `dialout`:

- **Immediate unblock, current shell only:**
  ```txt
  newgrp dialout
  ```
  This starts a new shell with `dialout` applied, without needing to log out. Any *already-running* `claude` session (started before you ran this) still won't have it — start a new `claude` session from within this same `newgrp`'d shell to pick it up.
- **Permanent fix, guaranteed to work everywhere (including whatever process hosts a `claude` session in an IDE/editor):**
  ```txt
  sudo reboot
  ```
  A full reboot is the only thing that reliably rebuilds *every* process's credentials from scratch. A desktop "log out" was not sufficient in testing — some session/manager state can persist across it. After rebooting, no `newgrp` or `chmod` is needed again, ever — this is a one-time fix.
- **One-off, if you can't reboot right now:**
  ```txt
  sudo chmod 666 /dev/ttyACM0
  ```
  (Resets on every replug — a stopgap, not a fix.)

**Gotcha: `|| true` hides this failure.** Every hook command ends in `|| true` (see `../../hooks/README.md`) so a disconnected device doesn't spam errors during normal use. This means Claude Code's own hook log (e.g. `PostCompact [andon-light set compacting || true] completed successfully`) will say "completed successfully" **even when the underlying `andon-light` call failed with exactly this permission error** — the hook process itself still exits 0. Don't trust that log line as proof the light actually changed; if you suspect this, run the `andon-light` command directly (without `|| true`) and check its real exit code.

## Step 3: is something else holding the port open?

```txt
andon-light set idle
```

**What it tells you:**

- Succeeds silently, exit code 0 → the CLI → firmware link works. If the physical LED still didn't change, the firmware itself may need reflashing (go to Step 1) or the pin wiring may not match the sketch (see `../firmware/README.md`).
- `andon-light: serial error: ... Device or resource busy` → another program has the port open — almost always Arduino IDE's Serial Monitor. Close it (there's a disconnect/plug icon in the Serial Monitor panel), then retry.

Check the exit code explicitly if the message scrolled past:

```txt
andon-light set idle; echo "exit code: $?"
```

## Step 4: is the hook config correct?

```txt
cat ~/.claude/settings.json
```

**What to check:**

- Is it valid JSON? Run:

```txt
python3 -c "import json; json.load(open('/home/sean/.claude/settings.json'))" && echo "VALID JSON"
```

If this errors, the file has a syntax mistake (usually a missing comma or brace) — Claude Code will likely ignore the whole `hooks` block until it's fixed.

- Does every hook command end in `|| true`? Without it, a hook failure (e.g. device unplugged) surfaces as noisy error output in Claude Code instead of failing silently.
- Are the hook commands **not** marked `"async": true`? Async was tried and reverted (2026-07-08) — it caused hook commands to complete out of order, leaving the light stuck on a stale color. See `../../hooks/README.md` "Why not async" for the full story.
- **Did you restart Claude Code after editing this file?** Hook config is only read when a Claude Code session starts — an already-running session will not pick up a config change. This is the single most common "why didn't it do anything" cause.

## Step 5: manually simulate what a hook would do

Useful to isolate "is it the light/CLI, or is it Claude Code's hooks" — run the exact commands a hook would run, by hand:

```txt
andon-light set working    # should go solid green
andon-light set waiting    # should go solid yellow
andon-light set idle       # should go solid red
andon-light set compacting # should go flashing green
```

If all four work correctly by hand but the light doesn't react during an actual Claude Code session, the problem is in the hook config (Step 4) or Claude Code not having picked it up yet (restart it) — not in the hardware or CLI.

## Launching Arduino IDE from a terminal

The Arduino IDE AppImage may fail to launch normally with a FUSE-related error (`dlopen(): error loading libfuse.so.2` or `Cannot mount AppImage`). If double-clicking it doesn't work, run this from a terminal instead — it bypasses the FUSE mount entirely:

```txt
cd ~/Downloads
./arduino-ide_2.3.10_Linux_64bit.AppImage --appimage-extract-and-run
```

(Adjust the filename if you've downloaded a different version.) It'll take a few seconds to extract and open; the window should appear on screen once it's ready. It restores your previously open sketch/tabs automatically.

## Reference: what "normal" looks like

For comparison, here's confirmed-working output from this project's actual hardware (a Waveshare RP2040-Zero), so you know what a healthy state looks like:

```txt
$ lsusb | grep 2e8a
Bus 005 Device 010: ID 2e8a:0003 Raspberry Pi RP2 Boot      # ← bootloader mode (bad if unexpected)
# vs., when firmware is running normally, lsusb won't show a distinct "RP2 Boot" line —
# check `udevadm info -a -n /dev/ttyACM0 | grep -iE "manufacturer|product"` instead:
#   ATTRS{manufacturer}=="Waveshare"
#   ATTRS{product}=="RP2040 Zero"

$ andon-light doctor
Found device on /dev/ttyACM0

$ andon-light set working; echo "exit=$?"
exit=0
```

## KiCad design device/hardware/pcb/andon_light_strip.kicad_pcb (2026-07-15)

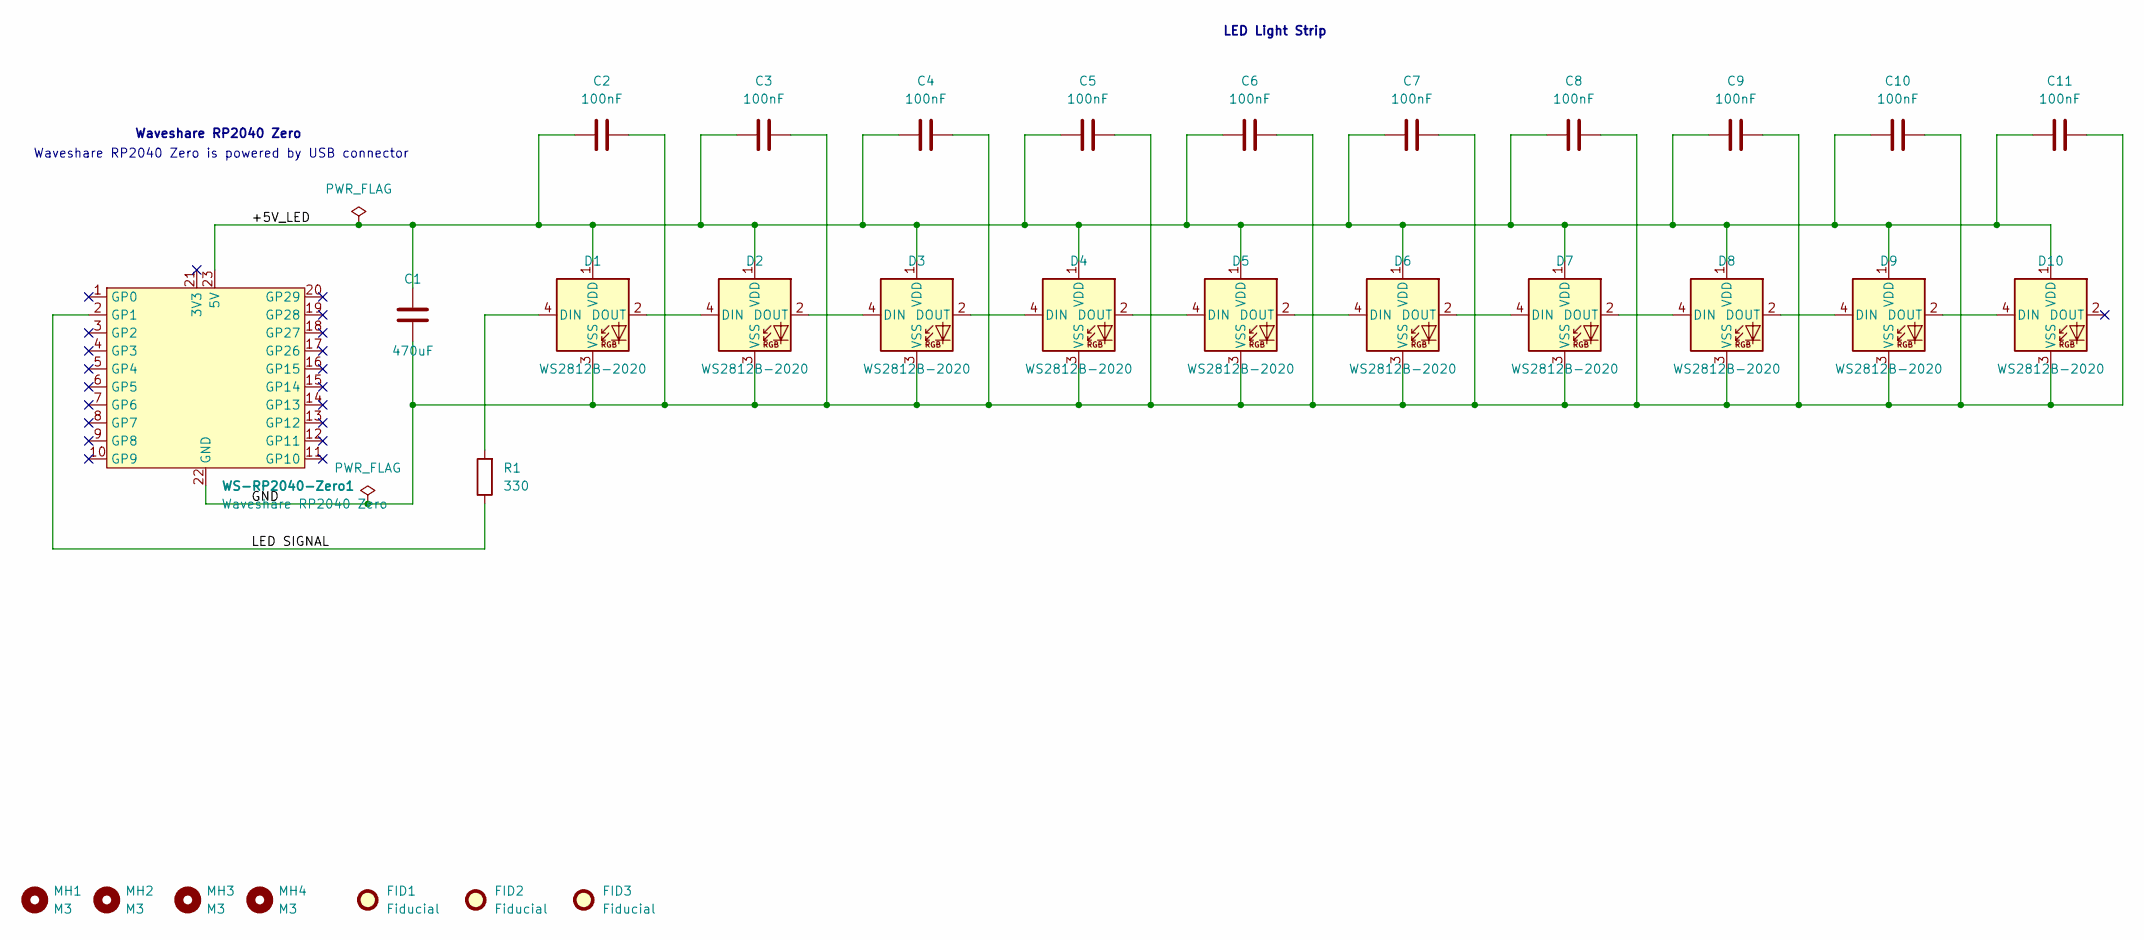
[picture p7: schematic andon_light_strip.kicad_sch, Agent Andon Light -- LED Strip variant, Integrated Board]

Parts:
C1: 470uF; CP_Elec_6.3x5.4; Manufacturer Part Number JVJ16V470M6x8; LCSC C46550400
C2, C3, C4, C5, C6, C7, C8, C9, C10, C11: 100nF; C_0402_1005Metric; Manufacturer Part Number CL05B104KB54PNC; LCSC C307331
D1, D2, D3, D4, D5, D6, D7, D8, D9, D10: WS2812B-2020; worldsemi-WS2812B-2020-V6; Manufacturer Part Number WS2812B-2020-V6; LCSC C52917434
FID1, FID2, FID3: Fiducial; Fiducial_1mm_Mask2mm
MH1, MH2, MH3, MH4: M3; MountingHole_3.2mm_M3_ISO7380
R1: 330; R_0805_2012Metric; Manufacturer Part Number RC0805FR-07330RL; LCSC C105878
WS-RP2040-Zero1: Waveshare RP2040 Zero; Manufacturer Part Number 20187; LCSC C5350143

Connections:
/+5V_LED: C1.1, C2.1, C3.1, C4.1, C5.1, C6.1, C7.1, C8.1, C9.1, C10.1, C11.1, D1.1 (VDD), D2.1 (VDD), D3.1 (VDD), D4.1 (VDD), D5.1 (VDD), D6.1 (VDD), D7.1 (VDD), D8.1 (VDD), D9.1 (VDD), D10.1 (VDD), WS-RP2040-Zero1.23 (5V)
/GND: C1.2, C2.2, C3.2, C4.2, C5.2, C6.2, C7.2, C8.2, C9.2, C10.2, C11.2, D1.3 (VSS), D2.3 (VSS), D3.3 (VSS), D4.3 (VSS), D5.3 (VSS), D6.3 (VSS), D7.3 (VSS), D8.3 (VSS), D9.3 (VSS), D10.3 (VSS), WS-RP2040-Zero1.22 (GND)
/LED SIGNAL: R1.1, WS-RP2040-Zero1.2 (GP1)
unnamed: D1.4 (DIN), R1.2
unnamed: D1.2 (DOUT), D2.4 (DIN)
unnamed: D2.2 (DOUT), D3.4 (DIN)
unnamed: D3.2 (DOUT), D4.4 (DIN)
unnamed: D4.2 (DOUT), D5.4 (DIN)
unnamed: D5.2 (DOUT), D6.4 (DIN)
unnamed: D6.2 (DOUT), D7.4 (DIN)
unnamed: D7.2 (DOUT), D8.4 (DIN)
unnamed: D8.2 (DOUT), D9.4 (DIN)
unnamed: D9.2 (DOUT), D10.4 (DIN)

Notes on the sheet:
LED Light Strip
Waveshare RP2040 Zero is powered by USB connector
Waveshare RP2040 Zero

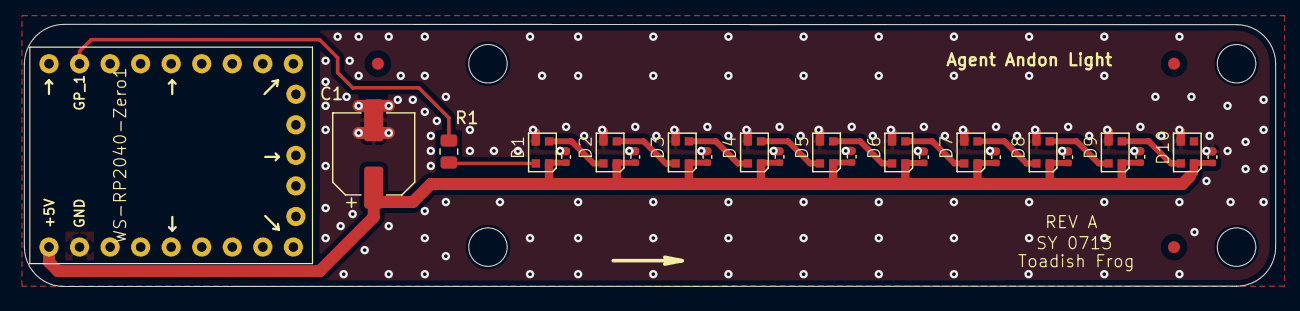
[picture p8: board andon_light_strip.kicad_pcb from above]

Board: 2 copper layers, 104.0 x 21.8 mm, 30 parts (0 on the bottom side), 13 nets.

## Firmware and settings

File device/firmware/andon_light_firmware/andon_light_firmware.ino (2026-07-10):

#include "led_controller.h"
#include "watchdog.h"

namespace {
constexpr uint8_t kDataPin = 1;    // GPIO1 — to the LED strip PCBA's "S" (signal) pin; confirm against your wiring
constexpr uint16_t kNumPixels = 10;  // WS2812-style strip PCBA, 10 addressable LEDs
constexpr uint32_t kWatchdogTimeoutMs = 1800000;  // 30 min — same value as the led-bulb variant;
                                                   // see ../../../led-bulb/firmware/README.md
constexpr unsigned long kSerialBaud = 115200;
}  // namespace

LedController leds(kDataPin, kNumPixels);
Watchdog watchdog(kWatchdogTimeoutMs);

void setup() {
  Serial.begin(kSerialBaud);
  leds.begin();
  watchdog.kick();
}

void loop() {
  while (Serial.available()) {
    switch (Serial.read()) {
      case 'G': leds.setColor(LightColor::Green);        watchdog.kick(); break;
      case 'Y': leds.setColor(LightColor::Yellow);       watchdog.kick(); break;
      case 'R': leds.setColor(LightColor::Red);          watchdog.kick(); break;
      case 'C': leds.setColor(LightColor::CompactFlash); watchdog.kick(); break;
      case 'H': watchdog.kick(); break;
      default: break;  // ignores '\n', '\r', and anything unrecognized
    }
  }

  if (watchdog.isStale()) {
    leds.setColor(LightColor::StalePulse);
  }
  leds.update();
}

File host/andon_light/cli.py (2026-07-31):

"""Command-line entry point for the andon-light host driver."""

from __future__ import annotations

import argparse
import sys

import serial

from .device_discovery import find_device_port
from .hooks_install import run as run_install_hooks
from .serial_link import SerialLink

COLOR_COMMANDS = {
    "working": "G",
    "waiting": "Y",
    "idle": "R",
    "compacting": "C",
}


def _resolve_port(explicit_port: str | None) -> str:
    if explicit_port:
        return explicit_port

    result = find_device_port()
    if result.port:
        return result.port
    if result.candidates:
        raise SystemExit(
            f"Multiple possible devices found: {result.candidates}. "
            "Pick one with --port or set ANDON_LIGHT_PORT."
        )
    raise SystemExit("No Andon Light device found. Plug it in, or pass --port explicitly.")


def cmd_set(args: argparse.Namespace) -> None:
    port = _resolve_port(args.port)
    with SerialLink(port) as link:
        link.send(COLOR_COMMANDS[args.state])


def cmd_heartbeat(args: argparse.Namespace) -> None:
    port = _resolve_port(args.port)
    with SerialLink(port) as link:
        link.send("H")


def cmd_doctor(_args: argparse.Namespace) -> None:
    result = find_device_port()
    if result.port:
        print(f"Found device on {result.port}")
    elif result.candidates:
        print(f"Multiple candidates, none auto-selected: {result.candidates}")
    else:
        print("No device found.")


def cmd_install_hooks(args: argparse.Namespace) -> int:
    return run_install_hooks(scope=args.scope, assume_yes=args.yes)


def build_parser() -> argparse.ArgumentParser:
    parser = argparse.ArgumentParser(prog="andon-light")
    parser.add_argument("--port", help="Explicit serial port, overrides auto-detection")
    subparsers = parser.add_subparsers(required=True)

    set_parser = subparsers.add_parser("set", help="Set the light's state")
    set_parser.add_argument("state", choices=COLOR_COMMANDS.keys())
    set_parser.set_defaults(func=cmd_set)

    heartbeat_parser = subparsers.add_parser(
        "heartbeat", help="Send a keepalive without changing color"
    )
    heartbeat_parser.set_defaults(func=cmd_heartbeat)

    doctor_parser = subparsers.add_parser(
        "doctor", help="Detect the device and report its port"
    )
    doctor_parser.set_defaults(func=cmd_doctor)

    install_hooks_parser = subparsers.add_parser(
        "install-hooks", help="Merge the Claude Code hooks into settings.json"
    )
    install_hooks_parser.add_argument(
        "--scope",
        choices=["global", "project"],
        default=None,
        help="global (~/.claude/settings.json) or project (./.claude/settings.json)",
    )
    install_hooks_parser.add_argument(
        "--yes",
        action="store_true",
        help="Skip confirmation prompts (requires --scope)",
    )
    install_hooks_parser.set_defaults(func=cmd_install_hooks)

    return parser


def main(argv: list[str] | None = None) -> int:
    parser = build_parser()
    args = parser.parse_args(argv)
    try:
        result = args.func(args)
    except serial.SerialException as exc:
        print(f"andon-light: serial error: {exc}", file=sys.stderr)
        return 1
    return result if isinstance(result, int) else 0


if __name__ == "__main__":
    sys.exit(main())

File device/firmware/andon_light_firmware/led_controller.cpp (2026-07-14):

#include "led_controller.h"

#include <math.h>

namespace {
constexpr uint32_t kPulsePeriodMs = 1200;   // StalePulse: slow breathing fade

// CompactFlash: a chase-fill sequence, not a blink. Each pass sweeps a single lit pixel
// down from silkscreen pixel 10 to pixel 2 (a "chase"), then locks that pass's bottom
// pixel on before starting the next pass — so pixels accumulate from pixel 2 upward, one
// per pass, until all 9 non-status pixels are lit, then the whole thing resets and
// repeats. kCompactPixelCount is all non-status pixels (array indices
// kGreenStart..kRedStart+kRedCount-1, i.e. 1-9, which are silkscreen pixels 2-10); pass k
// (array-index terms) sweeps (kCompactPixelCount - k) transient pixels then locks index k,
// so total steps across all kCompactPixelCount passes is the triangular number
// kCompactPixelCount + (kCompactPixelCount-1) + ... + 1.
constexpr uint32_t kCompactStepMs = 120;
constexpr uint16_t kCompactPixelCount = 9;
constexpr uint16_t kCompactTotalSteps = kCompactPixelCount * (kCompactPixelCount + 1) / 2;

// Base brightness cap (0-255), applied to every solid/animated color.
// WS2812 pixels are uncomfortably bright at 255/255 close up, and capping
// also keeps worst-case current draw well within what USB bus power can
// supply across 10 pixels. Raise if the strip is diffused/behind a cover.
constexpr uint8_t kBrightness = 130;

// Pixel layout (0-indexed; silkscreen/BOM label these 1-10). An andon light communicates
// state by which lamp is lit, not by turning every lamp the same color at once — so each
// color gets its own dedicated sub-range of the strip instead of using strip.fill() across
// all 10 pixels. See device/docs/Implementation-Summary.md "Addressable pixel layout".
constexpr uint16_t kStatusPixel = 0;   // pixel 1 — dim white, "board is powered and running"
constexpr uint16_t kGreenStart = 1;    // pixels 2-4
constexpr uint16_t kGreenCount = 3;
constexpr uint16_t kYellowStart = 4;   // pixels 5-7
constexpr uint16_t kYellowCount = 3;
constexpr uint16_t kRedStart = 7;      // pixels 8-10
constexpr uint16_t kRedCount = 3;

// Deliberately low per-channel value (pre-scaled again by kBrightness at show() time) —
// a status indicator, not a fourth state color, so it should read as clearly dimmer than
// any active G/Y/R section next to it.
constexpr uint8_t kDimWhiteLevel = 25;
}  // namespace

LedController::LedController(uint8_t dataPin, uint16_t numPixels)
    : strip_(numPixels, dataPin, NEO_GRB + NEO_KHZ800) {}

void LedController::begin() {
  strip_.begin();
  strip_.setBrightness(kBrightness);
  strip_.clear();
  strip_.show();  // all off until the first color, avoids a garbage-data flash on boot
  // Boot to Off (dim-white status pixel only, all sections dark) rather than a solid
  // section color — this is the strip variant's own "board is alive" signal, playing the
  // same role the bulb variant's boot-to-red does, just encoded as the always-on status
  // pixel instead of a section color. See device/docs/Implementation-Summary.md
  // "Addressable pixel layout" / "Boot behavior differs intentionally" for why.
  setColor(LightColor::Off);
}

void LedController::setColor(LightColor color) {
  bool alreadyAnimating = (color == LightColor::StalePulse || color == LightColor::CompactFlash) &&
                           color == current_;
  if (alreadyAnimating) {
    return;  // already animating this state — don't reset the animation phase every loop
  }
  current_ = color;

  switch (color) {
    case LightColor::Green:  renderSection(kGreenStart, kGreenCount, 0, 255, 0);     break;
    case LightColor::Yellow: renderSection(kYellowStart, kYellowCount, 255, 255, 0); break;
    case LightColor::Red:    renderSection(kRedStart, kRedCount, 255, 0, 0);         break;
    case LightColor::StalePulse:
    case LightColor::CompactFlash:
      pulsePhaseStartMs_ = millis();
      break;
    case LightColor::Off:
    default: renderSection(0, 0, 0, 0, 0); break;  // no section lit; status pixel still shown
  }
}

void LedController::update() {
  if (current_ == LightColor::StalePulse) {
    uint32_t elapsed = (millis() - pulsePhaseStartMs_) % kPulsePeriodMs;
    float phase = elapsed / static_cast<float>(kPulsePeriodMs);
    float brightness = 0.5f * (1.0f - cosf(phase * 2.0f * PI));  // 0..1 breathing curve
    renderSection(kRedStart, kRedCount, static_cast<uint8_t>(255 * brightness), 0, 0);
  } else if (current_ == LightColor::CompactFlash) {
    uint32_t step = ((millis() - pulsePhaseStartMs_) / kCompactStepMs) % kCompactTotalSteps;

    // Find which pass `step` falls in and the offset within it. Pass k (1-indexed) has
    // (kCompactPixelCount - k) transient steps followed by 1 lock step, so pass sizes count
    // down from kCompactPixelCount to 1 as k goes from 1 to kCompactPixelCount.
    uint16_t offset = step;
    uint16_t pass = 1;
    uint16_t passSize = kCompactPixelCount;
    while (offset >= passSize) {
      offset -= passSize;
      pass++;
      passSize = kCompactPixelCount - pass + 1;
    }
    uint16_t numTransient = kCompactPixelCount - pass;
    bool transientPhase = offset < numTransient;
    uint16_t filledCount = transientPhase ? (pass - 1) : pass;  // pixels 1..filledCount locked on
    // Sweep direction is top-down: the topmost unfilled pixel goes first each pass.
    uint16_t activeIndex = transientPhase ? (kRedStart + kRedCount - 1 - offset) : 0;

    for (uint16_t i = kGreenStart; i <= kRedStart + kRedCount - 1; i++) {
      bool lit = (i <= filledCount) || (transientPhase && i == activeIndex);
      strip_.setPixelColor(i, lit ? strip_.Color(0, 255, 0) : 0);
    }
    strip_.setPixelColor(kStatusPixel, strip_.Color(kDimWhiteLevel, kDimWhiteLevel, kDimWhiteLevel));
    strip_.show();
  }
}

void LedController::renderSection(uint16_t sectionStart, uint16_t sectionCount, uint8_t r, uint8_t g,
                                   uint8_t b) {
  for (uint16_t i = 0; i < strip_.numPixels(); i++) {
    if (i == kStatusPixel) continue;  // set once, below — never part of a color section
    bool inSection = i >= sectionStart && i < sectionStart + sectionCount;
    strip_.setPixelColor(i, inSection ? strip_.Color(r, g, b) : 0);
  }
  strip_.setPixelColor(kStatusPixel, strip_.Color(kDimWhiteLevel, kDimWhiteLevel, kDimWhiteLevel));
  strip_.show();
}

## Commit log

2026-07-07 feat: device boot now boot to a solid red light,
2026-07-10 feat: implement led strip variants.
2026-07-10 feat: led light strip firmware update
2026-07-10 doc: update BOM to include optional capactor and resistor for safety
2026-07-14 docs: update files to reflect project structure changes accordingly.
    [andon_light_strip.kicad_pcb, andon_light_strip.kicad_sch]
2026-07-14 chore: update footprint dependencies, added 3d model
    [andon_light_strip.kicad_pcb]
2026-07-14 chore: update footprint and symbol dependencies
    [andon_light_strip.kicad_sch]
2026-07-14 chore: update file structures.
    [andon_light_strip.kicad_pcb, andon_light_strip.kicad_sch]
2026-07-14 chore: rename "led-strip" to a more meaniful "device" for forlder
    [andon_light_strip.kicad_pcb, andon_light_strip.kicad_sch]
2026-07-15 feat: add step fils and stl file for the chassis
    [andon_light_chassis.FCStd, andon_light_chassis_base.step, andon_light_chassis_lid.step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]
2026-07-16 fix: wall now above 3D printing minimum threadhold.
    [andon_light_chassis.FCStd, andon_light_chassis_base.step, andon_light_chassis_lid.step]
2026-07-16 fix: walls clip into each other
    [andon_light_chassis.FCStd, andon_light_chassis_base.step, andon_light_chassis_lid.step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]
2026-07-16 docs: add rendered images and step files under model/ folder.
    [andon_light_chassis_base.step, andon_light_chassis_lid.step]
2026-07-31 feat: add install-hooks CLI, PyPI packaging, Windows installer tooling
    - New `andon-light install-hooks` subcommand: merges Claude Code hooks
    into settings.json with explicit confirmation, global/project scope,
    and conflict warnings before overwriting existing hook mappings.
    - Publish andon-light to PyPI (MIT license, LICENSE added).
    - Windows: PyInstaller build script + Inno Setup installer script,
    per-user install, PATH registration, finish-page install-hooks flow.
    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
2026-07-31 refactor!: fix writing and group files
    [andon_light_firmware.ino, led_controller.cpp]

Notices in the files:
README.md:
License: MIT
